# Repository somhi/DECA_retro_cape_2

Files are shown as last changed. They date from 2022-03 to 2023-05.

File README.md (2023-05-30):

# DECA Retro Cape 2

### (2 layer - MiSTer module SDRAM version)

DECA Retro Cape 2 is an addon for the [DECA FPGA](https://github.com/DECAfpga/DECA_board) development kit from Arrow/Terasic. The addon is connected to the Beaglebone Black connectors and hence the name of Cape as addons in the Beaglebone world are known.

This cape adds IO interface to the DECA board with all is needed to implement retro computers in this beautiful FPGA. Main IO interfaces are DB15 for VGA, PS2 for keyboard and mouse, DB9 for joystick, MiSTer memory connector, MiSTer user port.

Project has been developed with KiCAD 6.0. 

### Status

STATUS (29/01/23): Tests of v0.90 PCB work as expected, except for JP8 jumper (see [testing notes](testing_v0.90.md)). 

STATUS (26/12/22):  Finalized design v0.90 and production files including BOM and CPL.  See end of readme for changelog improvements from v0.71.

STATUS (07/04/22):  PCBs v0.71 received. Started [testing](testing.md).  Do not use without modifying voltage protections. Keyboard and Joystick (DB9 and USB3) protections must be redesigned in the next release.

STATUS (15/03/22):  prototype desing work finished. v0.71 gerbers sent to JLCPCB for manufacturing.

### Credits

I want to give credits to Tom Verbeure from whom I've taken his [original design  files](https://github.com/tomverbeure/arrow_deca_retro_cape) and adapted to my own design. Not much have been left from his design, but the name "DECA Retro Cape" remains.  

Thanks to rest of Hard Team DECA (C.Palmero & Rhoderik) and Telegram groups for the support received  during the development phase.

### **Schematic**

 [arrow_deca_retro_cape.pdf](arrow_deca_retro_cape.pdf) 

### **Features**

* VGA DAC 444
  *  Jumper to make use of VGA to SCART cables for 15 kHz RGB video

* Terasic 2x20 pin connector (for Mister SDRAM modules) + 3 pin for Dual SDRAM/SRAM 
* PS2 keyboard & mouse connectors
* Double Pmod (1/2) for peripherals (VGA Pmod, Hyperram, ...). 
  * Added four central pins for compatibility with RGB module of MuseLabs

* Pmod 3 (SPI + UART). Can act as Pmod host or peripheral 
* DETO Pmod (6 pin) for general usage (3 multiplexed pins)
* Game controller port (selection jumper to enable one or the other)
  * DB9 connector for joystick (Sega megadrive) (solder JP3 for A.Villena MiSTer DB9 addons)
  * USB3 User Port (for SNAC adapters SNES, Atari, ...)

* UART (Rx/Tx) header
* Power supply headers (5V, 3V3, 3V3 LDO, 2V5 LDO, 1V8 analog)

### **Important Usage notes**

* **Better do not connect/disconnect interfaces while the board is powered**
* **Do not connect two devices simultaneously into DB9 and USB3. Doing so may lead to unpredictabily results and damage the FPGA board**
* Prior to first power on it is required to solder jumpers JP2 (pins 3V3 and V) and JP7 (pin 5V and central pin). Read jumper selection notes below
* To use MiSTer memory modules place jumper JP6 to power supply 3V3 (and better left JP5 without jumper)
* Place jumper JP8 on desired interface (DB9 or USB3) for joystick usage. For USB3 jumper JP9 default is I/O.
* For USB3 SNAC adapters **do not** use the [SNAC level shifter adapter](https://manuferhi.com/p/snac-adapter-for-mister) as voltage protection is already included in the cape.
* For the rest of jumpers read jumper selection notes below. In case of doubt leave the default recommended position.
* There are a few signals with shared functions that cannot be used at the same time. Those signals are indicated in the PCB silkscreen with ( ) or *, **:
  * (1), (2) are shared between DETO PMOD and PMOD2
  * (3) is shared between DETO PMOD and the MUX signal of DB9 when JP3 is soldered
  * "**" only either DB9 or USB3 connector can be used at the same time (select it by jumper JP8)
  * "*" signals MISO, MOSI, CS2, SCK are shared between PMOD3 and the four pins of J2 and J3 located between pmods 2 & 3

### **Jumper Selection**

Defaults are OPEN (jumper not placed or not soldered) and CLOSED (jumper placed or soldered)

* JP1 jumper select Pmod 3 mode as peripheral (no jumper) or host (with jumper) [default is open]

* JP2 solder jumper selects 3V3 power supply from Deca board or from an optional LDO [default 3V3]. An optional 5V to 3V3 LDO can be soldered if the board cannot cope with the connected loads.

* JP3 solder jumper enables compatibility with Antonio Villena's MiSTer DB9 addons if soldered (MUX signal to allow two joysticks). Be careful, THIS OPTION IS UNTESTED [default open]

* JP4 jumper closed enables 5V at VGA pin 9 to make use of VGA to SCART cables for 15 kHz RGB video [default open]

* JP5 jumper closed power supply 2x20 Terasic connector with +5V [default open]

* JP6 jumper closed power supply 2x20 Terasic connector with +3V3 [default closed]

* JP7 solder jumper to select joystick power supply (5V or 2V5) [default 5V]

* JP8 jumper select either DB9 interface or USER IO (USB3). **Only one device can be connected at a time, otherwise might be damaged the FPGA board**

* JP9 jumper select USER IO pin 9 function (signal I/O or 3V3 power) [default I/O]

### 3D model

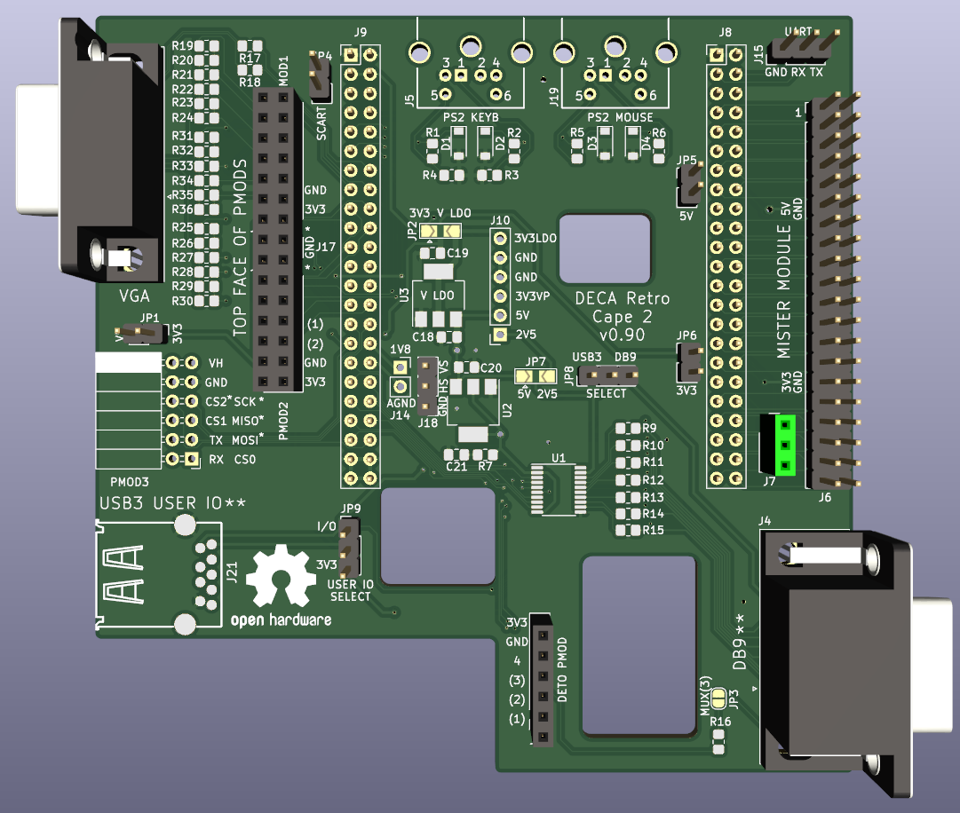
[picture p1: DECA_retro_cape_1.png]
DECA_retro_cape_1


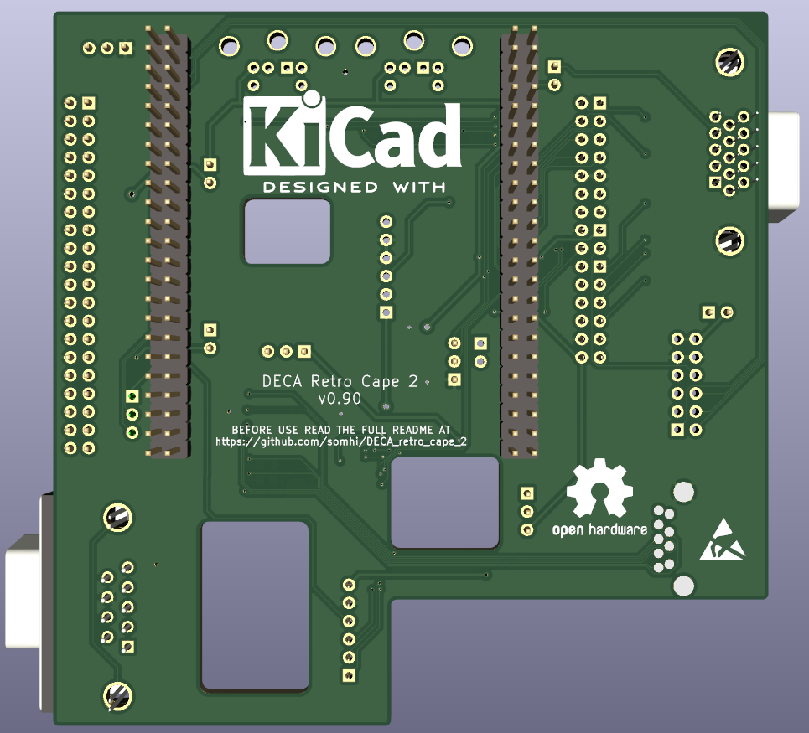
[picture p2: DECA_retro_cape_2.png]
DECA_retro_cape_2


### Changelog

v0.5  routed finalized

v0.6  MiSTer SDRAM only version. Changed to 2 layer board.

v0.62 all finished except VGA R2R schematic and routing

v0.65 power header changed, minor aesthetic changes

v0.68 added vga schematic and indiv. R 0805 into layout

v0.70 routing finished including vga

v0.71 finished prototype desing. Gerber sent to JLCPCB for manufacturing

v0.72 updated pinout spreadsheet and Readme with testing notes and improvements to be done

v0.75 Improvements from testing phase. 

* Changed footprint DB15 VGA to fit connectors from Aliexpress (was needed to bend pins)

* DETO Pmod connector change to socket type instead of pin type

* Silkscreen improvements: OSHW logo top

* Removed JTAG footprint

* Change limiting resistor of 180 Ohm to 510 Ohm (ps2 and db9)

* Power header reduced to 1 row instead of 2

* Optimized some traces

* Added solder pad JP3 to enable/disable compatibility with Antonio Villena's MiSTer DB9 addons

* JP4 jumper to enable 5V at VGA pin 9 to make use of VGA to SCART cables for 15 kHz RGB video

* Added PCB Hole for seeing Conf_done, Rx, Tx leds

v0.76 Double pmod 1&2 now compatible with pmod RGB module of MuseLabs (added 4 shared pins)

v0.77 Changes:

* Terasic connector: add jumpers on 5V and 3V3 to disconnect power, so I can connect it to other Terasic powered connectors.
* Replaced 3 pin jumper JP2 with solder jumper on 3V3 power selection
* Added solder jumper to select joystick power supply (5V or 2V5 from LDO)

v0.78 Changes:

* PS2 protection usign 3V9 Zener diodes (3V7 to 4V1).

* Added pulldown optional resistors for ps2 mouse

v0.80 Added Joystick shifter level protection with IC [TXS0108E](https://jlcpcb.com/partdetail/TexasInstruments-TXS0108EPWR/C17206) and jumper JP8 to select either DB9 or USB3 IO interface

v0.81 Improved Readme. Added readme notice in silkscreen. Removed v0.78 pulldown optional resistors for ps2 mouse (one of the pins has a physical pull-up resistor in fpga, so wouldn't work).

v0.82 generated BOM before installing jlcpcb-tools plugin

v0.83 Added jlcpcb parts with jlcpcb tools plugin 

v0.84 updated USB3 footprint

v0.85 updated references folder. choose zener 3V9 reference 

v0.86 updated datasheets, added R7 1Ω for increasing ESR on 2V5 LDO output with a ceramic capacitor instead of tantalum, updated BOM and nearly finished jlcpcb parts selection

v0.87 updated readme. Minor changes on schematic and PCB 

v0.90 Finalized design v0.90 and production files including BOM and CPL

### TODO improvements

* Reduce lenght of board in VGA wing side
* PS2:  Jumpers to activate pull-down resistors to enable USB mode
* If space is needed, make a common ps2 connector for keyb and mouse (ps2 splitter should be used). 
* Jumper on joystick DB9 pin 5 to change power supply to pin 7 in order to allow other joysticks like the Amiga one to work. Comment from telegram: "El Jumper lo puedes poner para cambiar la alimentación entre pin 5 y 7. De esa forma te funcionara ok los dos y podrás conectar cosas como el ratón de amiga. De los joysticks clásicos, la mayoría son totalmente pasivos y los quickshot II utilizan la alimentación de 5v para el autofire."
* SDRAM DQ14 and DQ15 position in newer MiSTer modules (xsds) are exchanged respect the older module (xs) I based my design from. This does not affect functionality at all as data in and data out are always in the same order.

### Testing

[Testings on v0.71 PCB](testing_v0.71.md)

[Testings on v0.90 PCB](testing_v0.90.md)

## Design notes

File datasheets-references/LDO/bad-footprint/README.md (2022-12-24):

U5 LDO 2V5 footprint do not correspond to LDO_2V5_NCV4274AST25T3G component

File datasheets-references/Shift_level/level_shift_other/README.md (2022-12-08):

Joystick shifter level protections

* jlc)  txs0108e, https://jlcpcb.com/partdetail/TexasInstruments-TXS0108EPWR/C17206
  74lvt245,  for 3v3
  jlc)  BSS138,    most polivalent edu, rhoderik alguns fallaven
  jlc) LSF0108  https://jlcpcb.com/partdetail/TexasInstruments-LSF0108PWR/C190219   2.5 V ↔ 3.3/5 V
  X) FXLP34P5XCT-ND     the ones used at UART C96

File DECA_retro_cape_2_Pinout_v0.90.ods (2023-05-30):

 |  |  |  | ←see pins in hidden columns |  |  |  |  |  | ←see pins in hidden columns
 |  | P9 |  |  |  |  |  | P8
 | GND | 1 | 2 | GND |  |  | GND | 1 | 2 | GND
 | 3V3 | 3 | 4 | 3V3 |  | pd7_fpga_en | UART_TXD | 3 | 4 | UART_RXD | pd6_core_reset
 | 5V | 5 | 6 | 5V |  | SPI_SS3 (OSD),pd10_cs | SPI_CS0_CLKBD | 5 | 6 | SPI_CS1 | CONF_DATA0 (IO), pd8_osd_en
 | 5V | 7 | 8 | 5V |  |  | DRAM_DQ[0] | 7 | 8 | DRAM_DQ[1]
10k pullup | PS2_MOUSE_DAT | 9 | 10 | PS2_MOUSE_CLK |  |  | DRAM_DQ[2] | 9 | 10 | DRAM_DQ[3]
 | PS2_KEYB_CLK | 11 | 12 | PS2_KEYB_DAT |  |  | DRAM_DQ[4] | 11 | 12 | DRAM_DQ[5]
 | VGA_VS / PMOD2[5] | 13 | 14 | VGA_HS / PMOD2[4] | RGB_PMOD_LCD_CLK |  | DRAM_DQ[6] | 13 | 14 | DRAM_DQ[7]
RGB_PMOD_g0 | VGA_B[0] / PMOD1[4] | 15 | 16 | VGA_R[0] / PMOD1[0] | RGB_PMOD_r0 |  | DRAM_DQ[14] | 15 | 16 | DRAM_DQ[15]
RGB_PMOD_b0 | VGA_G[0] / PMOD2[0] | 17 | 18 | VGA_G[3] / PMOD2[3] |  |  | DRAM_LDQM | 17 | 18 | DRAM_UDQM
 | VGA_G[2] / PMOD2[2] | 19 | 20 | VGA_G[1] / PMOD2[1] |  |  | DRAM_DQ[13] | 19 | 20 | DRAM_DQ[12]
RGB_PMOD_g3 | VGA_B[3] / PMOD1[7] | 21 | 22 | VGA_R[3] / PMOD1[3] | RGB_PMOD_r3 |  | DRAM_DQ[11] | 21 | 22 | DRAM_DQ[10]
 | VGA_B[2] / PMOD1[6] | 23 | 24 | VGA_R[2] / PMOD1[2] |  |  | DRAM_DQ[9] | 23 | 24 | DRAM_DQ[8]
 | VGA_B[1] / PMOD1[5] | 25 | 26 | VGA_R[1] / PMOD1[1] |  |  | DRAM_ADDR[12] | 25 | 26 | DRAM_CLK
SIGMA_L | DETO1 / PMOD2[6] | 27 | 28 | DETO2 / PMOD2[7] | SIGMA_R, BCLK |  | DRAM_ADDR[9] | 27 | 28 | DRAM_ADDR[11] | VREF slow
RGB_PMOD_R4, SPI_DO | SPI_MISO_WSDB | 29 | 30 | SPI_MOSI | SPI_DI, RGB_PMOD_G4 |  | DRAM_ADDR[7] | 29 | 30 | DRAM_ADDR[8]
RGB_PMOD_G5 | SPI_SCLK_DABD | 31 | 32 | A1V8 |  |  | DRAM_ADDR[5] | 31 | 32 | DRAM_ADDR[6]
AIN6/2V5 | JOYX_SEL_O | 33 | 34 | AGND |  |  | DRAM_WE_N | 33 | 34 | DRAM_ADDR[4]
AIN4/2V5 | JOY1_B2_P9 | 35 | 36 | JOY1_B1_P6 | AIN5/2V5 | LRCLK | DETO4 | 35 | 36 | DRAM_CKE
AIN2/2V5 | JOY1_UP | 37 | 38 | JOY1_DOWN | AIN3/2V5 |  | DRAM_CAS_N | 37 | 38 | DRAM_RAS_N
AIN0/2V5 | JOY1_RIGHT | 39 | 40 | JOY1_LEFT | AIN1/2V5 |  | DRAM_CS_N | 39 | 40 | DRAM_BA[0]
pll output, 3V3, DIN | DETO3_JOY_MUX | 41 | 42 | SPI_CS2 | SPI_SS2 (FPGA),pd9_io_en, RGB_PMOD_B0 |  | DRAM_BA[1] | 41 | 42 | DRAM_ADDR[10]
 | GND | 43 | 44 | GND |  |  | DRAM_ADDR[0] | 43 | 44 | DRAM_ADDR[1]
 | GND | 45 | 46 | GND |  |  | DRAM_ADDR[2] | 45 | 46 | DRAM_ADDR[3]
 | PMOD 1+2 (VGA/others) |  |  | PMOD3 (multicore) |  |  | 32 MB SDRAM embedded
 | 2 PS2 connectors + USB |  |  | DB9 (Joystick / AIN), USB3 Port
 | DETO PMOD (6 pin)
 | Design notes:
 | - Optional 3V3 from 5V (LDO 5 to 3V3)
 | - Header for power pins (5V, 3V3, GND, A1V8)
 | - Header DeTo for all 4 free pins (I2C, SPI, I2S, Sigma/delta)
 | - 40 pins Mister connector for external SRAM + 3 PINS
 | - USB3 User port shared with DB9
 | - test pins for VGA_VS/HS for connecting oscilloscope
 | - pulldown footprints in PS2 keyb for testing USB keyboards
 | USB3 Serial IO
 | https://boogermann.github.io/Bible_MiSTer/hardware/io-board/
 | https://manuferhi.com/search?q=snac |  |  |  |  |  | DECA RETRO CAPE 2 PINOUT v0.90
 | antoniovillena / MiSTer_DB9
 | https://github.com/antoniovillena/MiSTer_DB9

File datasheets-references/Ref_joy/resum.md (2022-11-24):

* mister: pull-ups al costat fpga, primer va la R limitadora
* R pull-up: 10k mister i minimig,  47k papilio

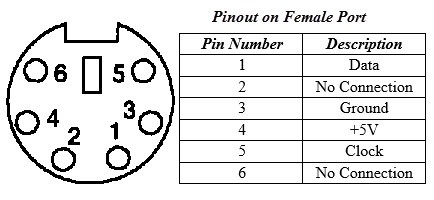
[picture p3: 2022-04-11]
datasheets-references/REF_circuits_connectors/ps2pinout.jpg

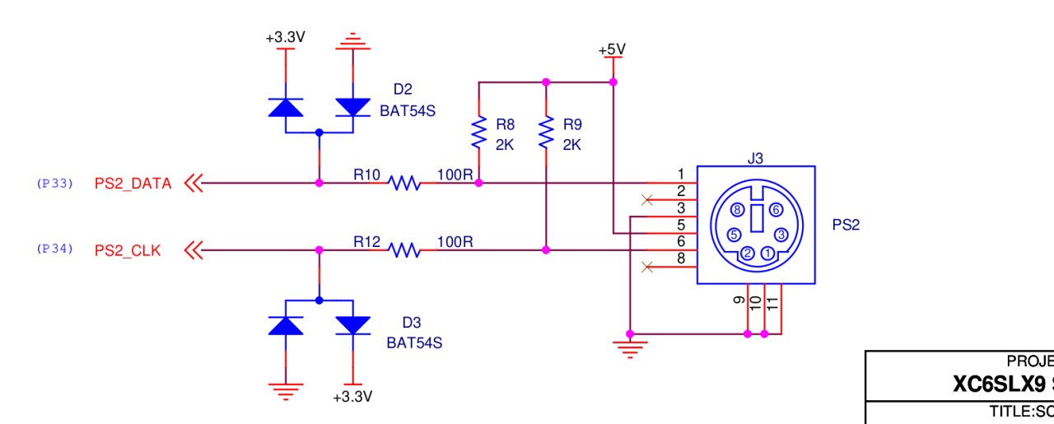
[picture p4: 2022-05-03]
datasheets-references/Ref_ps2/xc6slx9_placa_thesonders_BATs.jpg

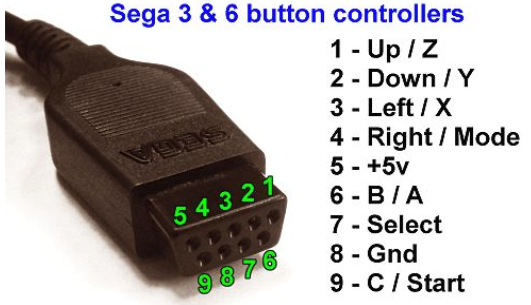
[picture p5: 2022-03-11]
datasheets-references/REF_circuits_connectors/db9-sega.png

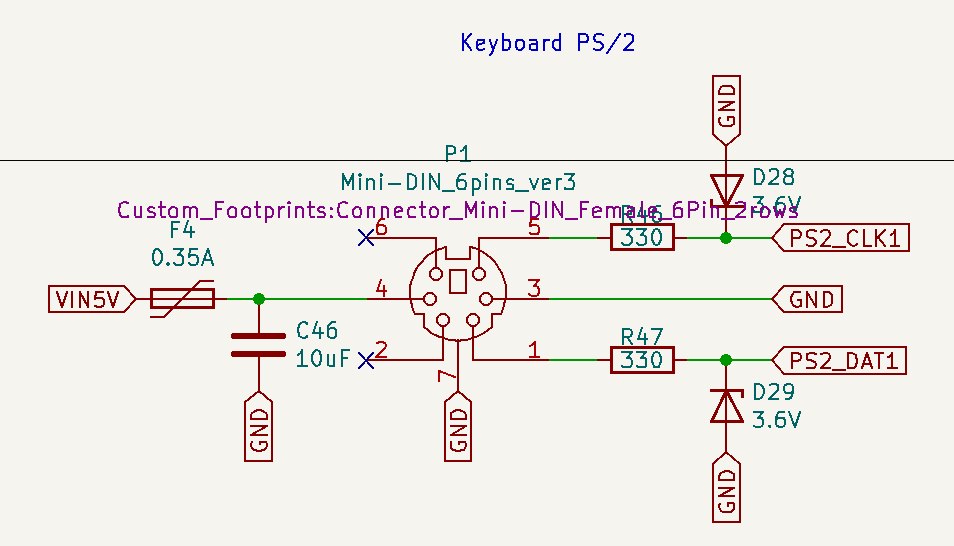
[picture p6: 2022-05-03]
datasheets-references/Ref_ps2/placa_minimig_zeners.jpg

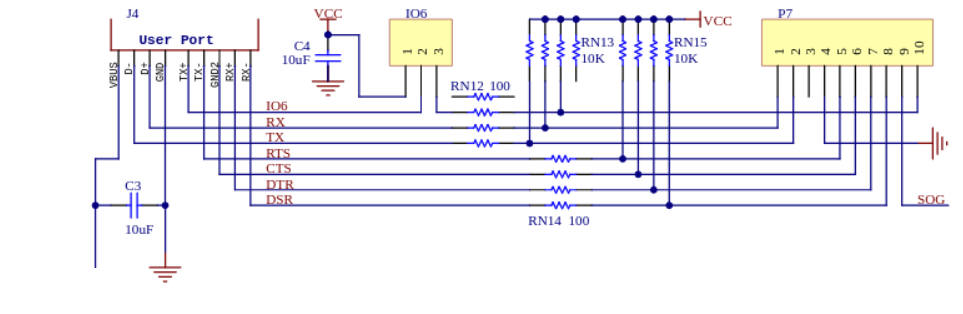
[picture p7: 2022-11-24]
datasheets-references/Ref_joy/mister_io_2.png

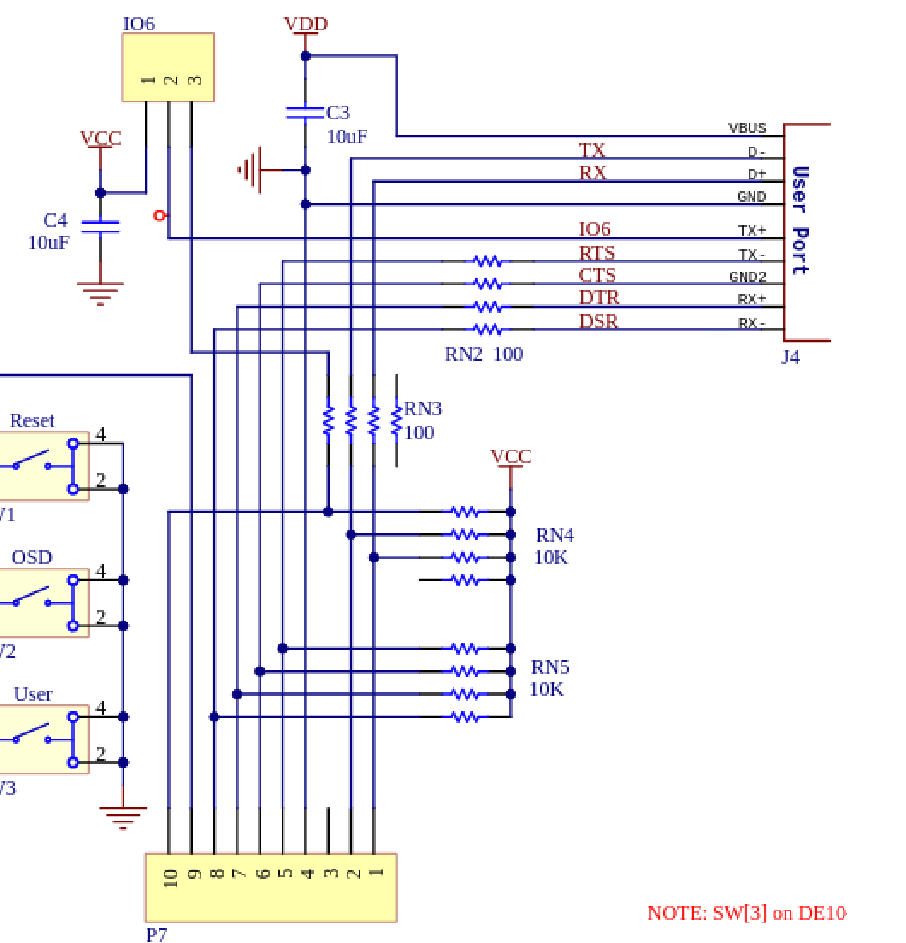
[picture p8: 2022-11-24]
datasheets-references/Ref_joy/mister_io_1.png

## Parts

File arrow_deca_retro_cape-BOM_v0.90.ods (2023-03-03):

Source: | /home/jordi/Kicad/a_DECA/DECA_retro_cape_2 (2-layer)/arrow_deca_retro_cape.kicad_sch
Date: | Sat 24 Dec 2022 20:08:38 CET
Tool: | Eeschema 6.0.9-8da3e8f707~117~ubuntu20.04.1
Generator: | /usr/share/kicad/plugins/bom_csv_grouped_by_value.py
Component Count: | 75
Individual Components:
Item | Qty | Reference(s) | Placed | https://jlcpcb.com/parts | notes | Value | LibPart | Footprint | Datasheet | Field4 | LCSC | Old | old_FP
 |  | C18 |  |  |  | 1uF | Device:C | Capacitor_SMD:C_0805_2012Metric_Pad1.18x1.45mm_HandSolder | ~
 |  | C19 |  |  |  | 10uF | Device:C | Capacitor_SMD:C_0805_2012Metric_Pad1.18x1.45mm_HandSolder | ~
 |  | C20 |  |  |  | 10uF | Device:C | Capacitor_SMD:C_0805_2012Metric_Pad1.18x1.45mm_HandSolder | ~
 |  | C21 |  |  |  | 22uF | Device:C | Capacitor_SMD:C_0805_2012Metric_Pad1.18x1.45mm_HandSolder | ~
 |  | D1 |  |  |  | BZT52C3V9 | :BZT52Bxx_1 | Diode_SMD:D_SOD-123 | https://datasheet.lcsc.com/lcsc/2005211208_LGE-BZT52C3V9_C545281.pdf
 |  | D2 |  |  |  | BZT52C3V9 | :BZT52Bxx_1 | Diode_SMD:D_SOD-123 | https://datasheet.lcsc.com/lcsc/2005211208_LGE-BZT52C3V9_C545281.pdf
 |  | D3 |  |  |  | BZT52C3V9 | :BZT52Bxx_1 | Diode_SMD:D_SOD-123 | https://datasheet.lcsc.com/lcsc/2005211208_LGE-BZT52C3V9_C545281.pdf
 |  | D4 |  |  |  | BZT52C3V9 | :BZT52Bxx_1 | Diode_SMD:D_SOD-123 | https://datasheet.lcsc.com/lcsc/2005211208_LGE-BZT52C3V9_C545281.pdf
 |  | J1 |  |  |  | DB15_Female_HighDensity_MountingHoles | Connector:DB15_Female_HighDensity_MountingHoles | Connector_Dsub:DSUB-15-HD_Female_Horizontal_P2.29x1.98mm_EdgePinOffset3.03mm_Housed_MountingHolesOffset4.94mm | ~
 |  | J2 |  |  |  | Conn_02x01 | Connector_Generic:Conn_02x01 | Connector_PinSocket_2.54mm:PinSocket_1x02_P2.54mm_Vertical | ~
 |  | J3 |  |  |  | Conn_02x01 | Connector_Generic:Conn_02x01 | Connector_PinSocket_2.54mm:PinSocket_1x02_P2.54mm_Vertical | ~
 |  | J4 |  |  |  | DB9_Male_MountingHoles | Connector:DB9_Male_MountingHoles | Connector_Dsub:DSUB-9_Male_Horizontal_P2.77x2.84mm_EdgePinOffset9.90mm_Housed_MountingHolesOffset11.32mm | ~
 |  | J5 |  |  |  | DINC_MIN_TM_6_1 | zxuno-eagle-import:DINC_MIN_TM_6_1 | ps2:DINC_MIN_TM_6_1PRIMARY
 |  | J6 |  |  |  | Conn_02x20_Odd_Even | Connector_Generic:Conn_02x20_Odd_Even | Connector_PinHeader_2.54mm:PinHeader_2x20_P2.54mm_Vertical | ~
 |  | J7 |  |  |  | Conn_01x03 | Connector_Generic:Conn_01x03 | Connector_PinSocket_2.54mm:PinSocket_1x03_P2.54mm_Vertical | ~
 |  | J8 |  |  |  | P8_Male | Connector_Generic:Conn_02x23_Odd_Even | Connector_PinHeader_2.54mm:PinHeader_2x23_P2.54mm_Vertical | ~
 |  | J9 |  |  |  | P9_Male | Connector_Generic:Conn_02x23_Odd_Even | Connector_PinHeader_2.54mm:PinHeader_2x23_P2.54mm_Vertical | ~
 |  | J10 |  |  |  | Conn_02x06_Odd_Even | Connector_Generic:Conn_01x06 | Connector_PinSocket_2.54mm:PinSocket_1x06_P2.54mm_Vertical | ~
 |  | J11 |  |  |  | PMOD1 | Connector_Generic:Conn_02x06_Top_Bottom | addon-edge-rpi-i2s-pmod:Pmod_2x06_P2.54mm_Vertical_2 | ~
 |  | J12 |  |  |  | PMOD2 | Connector_Generic:Conn_02x06_Top_Bottom | addon-edge-rpi-i2s-pmod:Pmod_2x06_P2.54mm_Vertical_2 | ~
 |  | J14 |  |  |  | Conn_01x02 | Connector_Generic:Conn_01x02 | Connector_PinSocket_2.54mm:PinSocket_1x02_P2.54mm_Vertical | ~
 |  | J15 |  |  |  | Conn_01x03 | Connector_Generic:Conn_01x03 | Connector_PinHeader_2.54mm:PinHeader_1x03_P2.54mm_Vertical | ~
 |  | J16 |  |  |  | Conn_01x06 | Connector_Generic:Conn_01x06 | Connector_PinSocket_2.54mm:PinSocket_1x06_P2.54mm_Vertical | ~
 |  | J17 |  |  |  | Conn_01x02 | Connector_Generic:Conn_01x02 | Connector_PinSocket_2.54mm:PinSocket_1x02_P2.54mm_Vertical | ~
 |  | J18 |  |  |  | Conn_01x03 | Connector_Generic:Conn_01x03 | Connector_PinHeader_2.54mm:PinHeader_1x03_P2.54mm_Vertical | ~
 |  | J19 |  |  |  | DINC_MIN_TM_6_1 | zxuno-eagle-import:DINC_MIN_TM_6_1 | ps2:DINC_MIN_TM_6_1PRIMARY
 |  | J20 |  |  |  | PMOD3 | Connector_Generic:Conn_02x06_Top_Bottom | addon-edge-rpi-i2s-pmod:PMOD_Female_Horizontal_2 | ~
 |  | J21 |  |  |  | USB3_A | Connector:USB3_A | varis:USB-3.0-TH_C69073 | ~ |  |  |  | Connector_USB:USB3_A_Molex_48393-001
 |  | J22 |  |  |  | Conn_01x03 | Connector_Generic:Conn_01x03 | Connector_PinHeader_2.54mm:PinHeader_1x03_P2.54mm_Vertical | ~
 |  | JP1 |  |  |  | Conn_01x02 | Connector_Generic:Conn_01x02 | Connector_PinHeader_2.54mm:PinHeader_1x02_P2.54mm_Vertical | ~
 |  | JP2 |  |  |  | SolderJumper_3_Open | Jumper:SolderJumper_3_Open | Jumper:SolderJumper-3_P2.0mm_Open_TrianglePad1.0x1.5mm | ~
 |  | JP3 |  |  |  | SolderJumper_2_Open | Jumper:SolderJumper_2_Open | Jumper:SolderJumper-2_P1.3mm_Open_RoundedPad1.0x1.5mm | ~
 |  | JP4 |  |  |  | Conn_01x02 | Connector_Generic:Conn_01x02 | Connector_PinHeader_2.54mm:PinHeader_1x02_P2.54mm_Vertical | ~
 |  | JP5 |  |  |  | Conn_01x02 | Connector_Generic:Conn_01x02 | Connector_PinHeader_2.54mm:PinHeader_1x02_P2.54mm_Vertical | ~
 |  | JP6 |  |  |  | Conn_01x02 | Connector_Generic:Conn_01x02 | Connector_PinHeader_2.54mm:PinHeader_1x02_P2.54mm_Vertical | ~
 |  | JP7 |  |  |  | SolderJumper_3_Open | Jumper:SolderJumper_3_Open | Jumper:SolderJumper-3_P2.0mm_Open_TrianglePad1.0x1.5mm | ~
 |  | JP8 |  |  |  | Conn_01x03 | Connector_Generic:Conn_01x03 | Connector_PinHeader_2.54mm:PinHeader_1x03_P2.54mm_Vertical | ~
 |  | R1 |  |  |  | 510 | Device:R | Resistor_SMD:R_0805_2012Metric_Pad1.20x1.40mm_HandSolder | ~ | Antonio entre 120 i 180 Ohm (47 també)
 |  | R2 |  |  |  | 510 | Device:R | Resistor_SMD:R_0805_2012Metric_Pad1.20x1.40mm_HandSolder | ~ | Antonio entre 120 i 180 Ohm (47 també)
 |  | R3 |  |  |  | DNI 4k7 | Device:R | Resistor_SMD:R_0805_2012Metric_Pad1.20x1.40mm_HandSolder | ~
 |  | R4 |  |  |  | DNI 4k7 | Device:R | Resistor_SMD:R_0805_2012Metric_Pad1.20x1.40mm_HandSolder | ~
 |  | R5 |  |  |  | 510 | Device:R | Resistor_SMD:R_0805_2012Metric_Pad1.20x1.40mm_HandSolder | ~ | Antonio entre 120 i 180 Ohm (47 també)
 |  | R6 |  |  |  | 510 | Device:R | Resistor_SMD:R_0805_2012Metric_Pad1.20x1.40mm_HandSolder | ~ | Antonio entre 120 i 180 Ohm (47 també)
 |  | R7 |  |  |  | 1 | Device:R | Resistor_SMD:R_0805_2012Metric_Pad1.20x1.40mm_HandSolder | ~
 |  | R9 |  |  |  | 510 | Device:R | Resistor_SMD:R_0805_2012Metric_Pad1.20x1.40mm_HandSolder | ~ | Antonio entre 120 i 180 Ohm (47 també)
 |  | R10 |  |  |  | 510 | Device:R | Resistor_SMD:R_0805_2012Metric_Pad1.20x1.40mm_HandSolder | ~ | Antonio entre 120 i 180 Ohm (47 també)
 |  | R11 |  |  |  | 510 | Device:R | Resistor_SMD:R_0805_2012Metric_Pad1.20x1.40mm_HandSolder | ~ | Antonio entre 120 i 180 Ohm (47 també)
 |  | R12 |  |  |  | 510 | Device:R | Resistor_SMD:R_0805_2012Metric_Pad1.20x1.40mm_HandSolder | ~ | Antonio entre 120 i 180 Ohm (47 també)
 |  | R13 |  |  |  | 510 | Device:R | Resistor_SMD:R_0805_2012Metric_Pad1.20x1.40mm_HandSolder | ~ | Antonio entre 120 i 180 Ohm (47 també)
 |  | R14 |  |  |  | 510 | Device:R | Resistor_SMD:R_0805_2012Metric_Pad1.20x1.40mm_HandSolder | ~ | Antonio entre 120 i 180 Ohm (47 també)
 |  | R15 |  |  |  | 510 | Device:R | Resistor_SMD:R_0805_2012Metric_Pad1.20x1.40mm_HandSolder | ~ | Antonio entre 120 i 180 Ohm (47 també)
 |  | R16 |  |  |  | 510 | Device:R | Resistor_SMD:R_0805_2012Metric_Pad1.20x1.40mm_HandSolder | ~ | Antonio entre 120 i 180 Ohm (47 també)
 |  | R17 |  |  |  | 180 | Device:R | Resistor_SMD:R_0805_2012Metric_Pad1.20x1.40mm_HandSolder | ~
 |  | R18 |  |  |  | 180 | Device:R | Resistor_SMD:R_0805_2012Metric_Pad1.20x1.40mm_HandSolder | ~
 |  | R19 |  |  |  | 2k | Device:R | Resistor_SMD:R_0805_2012Metric_Pad1.20x1.40mm_HandSolder | ~
 |  | R20 |  |  |  | 2k | Device:R | Resistor_SMD:R_0805_2012Metric_Pad1.20x1.40mm_HandSolder | ~
 |  | R21 |  |  |  | 2k | Device:R | Resistor_SMD:R_0805_2012Metric_Pad1.20x1.40mm_HandSolder | ~
 |  | R22 |  |  |  | 1k | Device:R | Resistor_SMD:R_0805_2012Metric_Pad1.20x1.40mm_HandSolder | ~
 |  | R23 |  |  |  | 1k | Device:R | Resistor_SMD:R_0805_2012Metric_Pad1.20x1.40mm_HandSolder | ~
 |  | R24 |  |  |  | 1k | Device:R | Resistor_SMD:R_0805_2012Metric_Pad1.20x1.40mm_HandSolder | ~
 |  | R25 |  |  |  | 2k | Device:R | Resistor_SMD:R_0805_2012Metric_Pad1.20x1.40mm_HandSolder | ~
 |  | R26 |  |  |  | 2k | Device:R | Resistor_SMD:R_0805_2012Metric_Pad1.20x1.40mm_HandSolder | ~
 |  | R27 |  |  |  | 2k | Device:R | Resistor_SMD:R_0805_2012Metric_Pad1.20x1.40mm_HandSolder | ~
 |  | R28 |  |  |  | 1k | Device:R | Resistor_SMD:R_0805_2012Metric_Pad1.20x1.40mm_HandSolder | ~
 |  | R29 |  |  |  | 1k | Device:R | Resistor_SMD:R_0805_2012Metric_Pad1.20x1.40mm_HandSolder | ~
 |  | R30 |  |  |  | 1k | Device:R | Resistor_SMD:R_0805_2012Metric_Pad1.20x1.40mm_HandSolder | ~
 |  | R31 |  |  |  | 2k | Device:R | Resistor_SMD:R_0805_2012Metric_Pad1.20x1.40mm_HandSolder | ~
 |  | R32 |  |  |  | 2k | Device:R | Resistor_SMD:R_0805_2012Metric_Pad1.20x1.40mm_HandSolder | ~
 |  | R33 |  |  |  | 2k | Device:R | Resistor_SMD:R_0805_2012Metric_Pad1.20x1.40mm_HandSolder | ~
 |  | R34 |  |  |  | 1k | Device:R | Resistor_SMD:R_0805_2012Metric_Pad1.20x1.40mm_HandSolder | ~
 |  | R35 |  |  |  | 1k | Device:R | Resistor_SMD:R_0805_2012Metric_Pad1.20x1.40mm_HandSolder | ~
 |  | R36 |  |  |  | 1k | Device:R | Resistor_SMD:R_0805_2012Metric_Pad1.20x1.40mm_HandSolder | ~
 |  | U1 |  |  |  | TXS0108EPW | Logic_LevelTranslator:TXS0108EPW | Package_SO:TSSOP-20_4.4x6.5mm_P0.65mm | www.ti.com/lit/ds/symlink/txs0108e.pdf
 |  | U4 |  |  |  | LM1117-3.3 | Regulator_Linear:LM1117-3.3 | Package_TO_SOT_SMD:SOT-223-3_TabPin2 | http://www.ti.com/lit/ds/symlink/lm1117.pdf
 |  | U5 |  |  |  | AMS1117-2.5 | Regulator_Linear:LM1117-3.3 | Package_TO_SOT_SMD:SOT-223-3_TabPin2 | http://www.ti.com/lit/ds/symlink/lm1117.pdf |  |  | LM1117-2.5
 |  |  |  |  | SMD = assembled by JLCPCB
Collated Components: |  |  |  |  | DNI = Do Not Install
Item | Qty | Reference(s) | Placed | https://jlcpcb.com/parts | notes | Value | LibPart | Footprint | Datasheet | Field4 | LCSC | Old | old_FP
1 | 1 | C18 |  | C28323 | SMD | 1uF | Device:C | Capacitor_SMD:C_0805_2012Metric_Pad1.18x1.45mm_HandSolder | ~
2 | 2 | C19, C20 |  | C15850 | SMD | 10uF | Device:C | Capacitor_SMD:C_0805_2012Metric_Pad1.18x1.45mm_HandSolder | ~
3 | 1 | C21 |  | C45783 | SMD | 22uF | Device:C | Capacitor_SMD:C_0805_2012Metric_Pad1.18x1.45mm_HandSolder | ~
4 | 4 | D1, D2, D3, D4 |  | C107594 | SMD | BZT52C3V9 | :BZT52Bxx_1 | Diode_SMD:D_SOD-123 | https://datasheet.lcsc.com/lcsc/2005211208_LGE-BZT52C3V9_C545281.pdf
5 | 1 | J1 |  |  | https://es.aliexpress.com/item/4000945346804.html | DB15_Female_HighDensity_MountingHoles | Connector:DB15_Female_HighDensity_MountingHoles | Connector_Dsub:DSUB-15-HD_Female_Horizontal_P2.29x1.98mm_EdgePinOffset3.03mm_Housed_MountingHolesOffset4.94mm | ~
6 | 2 | J2, J3 |  |  | DNI | Conn_02x01 | Connector_Generic:Conn_02x01 | Connector_PinSocket_2.54mm:PinSocket_1x02_P2.54mm_Vertical | ~
7 | 1 | J4 |  |  | https://es.aliexpress.com/item/33032596922.html | DB9_Male_MountingHoles | Connector:DB9_Male_MountingHoles | Connector_Dsub:DSUB-9_Male_Horizontal_P2.77x2.84mm_EdgePinOffset9.90mm_Housed_MountingHolesOffset11.32mm | ~
8 | 2 | J5, J19 |  |  | https://es.aliexpress.com/item/1005003218198326.html | DINC_MIN_TM_6_1 | zxuno-eagle-import:DINC_MIN_TM_6_1 | ps2:DINC_MIN_TM_6_1PRIMARY
9 | 1 | J6 |  |  | https://es.aliexpress.com/item/32759414721.html | Conn_02x20_Odd_Even | Connector_Generic:Conn_02x20_Odd_Even | Connector_PinHeader_2.54mm:PinHeader_2x20_P2.54mm_Vertical | ~
10 | 1 | J7 |  |  | https://es.aliexpress.com/item/1005003183490511.html | Conn_01x03 | Connector_Generic:Conn_01x03 | Connector_PinSocket_2.54mm:PinSocket_1x03_P2.54mm_Vertical | ~
11 | 1 | J8 |  |  | https://es.aliexpress.com/item/32759414721.html | P8_Male | Connector_Generic:Conn_02x23_Odd_Even | Connector_PinHeader_2.54mm:PinHeader_2x23_P2.54mm_Vertical | ~
12 | 1 | J9 |  |  | https://es.aliexpress.com/item/32759414721.html | P9_Male | Connector_Generic:Conn_02x23_Odd_Even | Connector_PinHeader_2.54mm:PinHeader_2x23_P2.54mm_Vertical | ~
13 | 1 | J10 |  |  | DNI | Conn_02x06_Odd_Even | Connector_Generic:Conn_01x06 | Connector_PinSocket_2.54mm:PinSocket_1x06_P2.54mm_Vertical | ~
14 | 1 | J11 |  | 2x15 socket |  | PMOD1 | Connector_Generic:Conn_02x06_Top_Bottom | addon-edge-rpi-i2s-pmod:Pmod_2x06_P2.54mm_Vertical_2 | ~
15 | 1 | J12 |  | 2x15 socket |  | PMOD2 | Connector_Generic:Conn_02x06_Top_Bottom | addon-edge-rpi-i2s-pmod:Pmod_2x06_P2.54mm_Vertical_2 | ~
16 | 2 | J14, J17 |  | J14 DNI, J17 2x15 socket | https://es.aliexpress.com/item/1005001914815306.html | Conn_01x02 | Connector_Generic:Conn_01x02 | Connector_PinSocket_2.54mm:PinSocket_1x02_P2.54mm_Vertical | ~
17 | 4 | J15, J18, JP8, JP9 |  |  | https://es.aliexpress.com/item/32759414721.html | Conn_01x03 | Connector_Generic:Conn_01x03 | Connector_PinHeader_2.54mm:PinHeader_1x03_P2.54mm_Vertical | ~
18 | 1 | J16 |  |  | https://es.aliexpress.com/item/1005001914815306.html | Conn_01x06 | Connector_Generic:Conn_01x06 | Connector_PinSocket_2.54mm:PinSocket_1x06_P2.54mm_Vertical | ~
19 | 1 | J20 |  |  | https://es.aliexpress.com/item/32890057619.html | PMOD3 | Connector_Generic:Conn_02x06_Top_Bottom | addon-edge-rpi-i2s-pmod:PMOD_Female_Horizontal_2 | ~
20 | 1 | J21 |  | C69073 | https://es.aliexpress.com/item/32663319053.html | USB3_A | Connector:USB3_A | varis:USB-3.0-TH_C69073 | ~ |  |  |  | Connector_USB:USB3_A_Molex_48393-001
21 | 4 | JP1, JP4, JP5, JP6 |  |  | https://es.aliexpress.com/item/32759414721.html | Conn_01x02 | Connector_Generic:Conn_01x02 | Connector_PinHeader_2.54mm:PinHeader_1x02_P2.54mm_Vertical | ~
22 | 2 | JP2, JP7 |  |  | -- | SolderJumper_3_Open | Jumper:SolderJumper_3_Open | Jumper:SolderJumper-3_P2.0mm_Open_TrianglePad1.0x1.5mm | ~
23 | 1 | JP3 |  |  | -- | SolderJumper_2_Open | Jumper:SolderJumper_2_Open | Jumper:SolderJumper-2_P1.3mm_Open_RoundedPad1.0x1.5mm | ~
24 | 12 | R1, R2, R5, R6, R9, R10, R11, R12, R13, R14, R15, R16 |  | C17734 | SMD | 510 | Device:R | Resistor_SMD:R_0805_2012Metric_Pad1.20x1.40mm_HandSolder | ~ | Antonio entre 120 i 180 Ohm (47 també)
25 | 2 | R3, R4 |  |  | DNI | DNI 4k7 | Device:R | Resistor_SMD:R_0805_2012Metric_Pad1.20x1.40mm_HandSolder | ~
26 | 1 | R7 |  | C25271 | SMD | 1 | Device:R | Resistor_SMD:R_0805_2012Metric_Pad1.20x1.40mm_HandSolder | ~
27 | 2 | R17, R18 |  | C25270 | SMD | 180 | Device:R | Resistor_SMD:R_0805_2012Metric_Pad1.20x1.40mm_HandSolder | ~
28 | 9 | R19, R20, R21, R25, R26, R27, R31, R32, R33 |  | C17604 | SMD | 2k | Device:R | Resistor_SMD:R_0805_2012Metric_Pad1.20x1.40mm_HandSolder | ~
29 | 9 | R22, R23, R24, R28, R29, R30, R34, R35, R36 |  | C17513 | SMD | 1k | Device:R | Resistor_SMD:R_0805_2012Metric_Pad1.20x1.40mm_HandSolder | ~
30 | 1 | U1 |  | C17206 | SMD | TXS0108EPWR | Logic_LevelTranslator:TXS0108EPW | Package_SO:TSSOP-20_4.4x6.5mm_P0.65mm | www.ti.com/lit/ds/symlink/txs0108e.pdf
31 | 1 | U3 |  |  | DNI | LM1117-3.3 | Regulator_Linear:LM1117-3.3 | Package_TO_SOT_SMD:SOT-223-3_TabPin2 | http://www.ti.com/lit/ds/symlink/lm1117.pdf
32 | 1 | U2 |  | C12087 | SMD | AMS1117-2.5 | Regulator_Linear:LM1117-3.3 | Package_TO_SOT_SMD:SOT-223-3_TabPin2 | http://www.ti.com/lit/ds/symlink/lm1117.pdf |  |  | LM1117-2.5
 | 6 | JUMPERS |  |  | https://es.aliexpress.com/item/10000002338839.html | JUMPERS

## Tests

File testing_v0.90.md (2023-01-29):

# Testing DECA Retro Cape 2 

## Tests v0.90 PCB

- [x] DB15 VGA connector
  - [x] SCART JP4 jumper (5V on pin 9) to activate TVs for 15 KHz video output (test: PCXT, Pooyan)
  
- [x] Mister module connector: tested with dual memory module and XS 2.2
  - [x] 3 extra pins. Test with dual memory module
  - [x] JP6 jumper for 3V3 power supply
  - [x] JP5 jumper for 5V power supply
  
- [x] PS2 mouse: PCXT, MiSTery
  - [x] voltage on FPGA pins < 3V3 (Test: 2.75 V)
  
- [x] PS2 keyboard: all cores tested
  - [x] voltage on FPGA pins < 3V3.  (Test: 3.16V)
  
- [x] DB9 / USB3
  
  - [x] Without joystick connected, keyboard is working fine
  
  - [x] DB9 joystick  (tested with megadrive 6 buttons) (Pooyan, SNES 6 buttons test)
    - [x] voltage on FPGA pins < 2V5  (test: 2.49V)
    - [ ] DB9 Mux JP3 solder jumper for Villena addons compatibility  **(untested)**
  
  - [x] USB3 user IO: tested with USB3 to DB9 SNAC  (tested with megadrive 6 buttons) (SNES 6 buttons test)
    - [x] voltage on FPGA pins < 2V5
    - [x] JP9 I/O 
    - [ ] JP9 3V3 **(untested)**

  - [x] DB9 / USB3 JP8 jumper selection  **(gives undesired results)**
  
    Without any jumper placed, if I connect a megadrive pad either to DB9 or USB3 it works and the corresponing pin of the jumper (USB3 / DB9)  gets 5V though the gamepad itself.
  
    **CAUTION: Do not connect devices simultaneously into DB9 and USB3 connectors. Doing so may lead to unpredictabily results and damage the FPGA board.**
  
- [x] PMOD
  - [x] Pmod 1 (tested with Pmod VGA digilent)

  - [x] Pmod 2 (tested with Pmod VGA digilent)

  - [x] Pmod 3
    - [x] JP1 jumper to act as Pmod host

  - [ ] Pmod DETO

  - [x] Extended pins for Pmod1 & Pmod2 

    - [x] 5V
    - [ ] 4 extra central pins for e.g.  RGB module of MuseLabs

- [x] UART Serial connector J15

- [x] Power supply connector J10
  - [x] 2V5 (LDO)
  - [x] 5V (FPGA)
  - [x] 3V3VP (FPGA)
  - [x] GND
  - [x] 3V3LDO (LDO) (0V as LDO is not assembled)

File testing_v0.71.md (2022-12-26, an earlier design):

# Testing DECA Retro Cape 2 

## Tests v0.71 PCB

* 2V5 LDO gives 2.5 without connecting Deca. With Deca connected output goes to 2.74 V. With Sega megadrive connected goes to 2.64 V. With Atari joystick 2.74V.

**19/04/22** Test circuit amb BATs

* En buit, pin ps2_keyb_dat, a 4.8V tant amb el BAT abans con després de la R (idem resultats amb R 180 i amb R 470)

* En càrrega (deca connectada), pin ps2_keyb_dat, a 4.8V tant amb el BAT abans con després de la R (idem 180 i 470)

* Posant R pullup (i sense BATs) tal com esquema Tom Verbeure també obtinc 5V als pins FPGA. Provat amb 4k7 i 10k.    També he provat de simular impedància FPGA posant una R de 1 MOhm entre pin FPGA i GND, amb resultats similars.

**25/04/22**  Test esquema tipus Tom Verbeure retrocape, amb Deca connectada a la cape

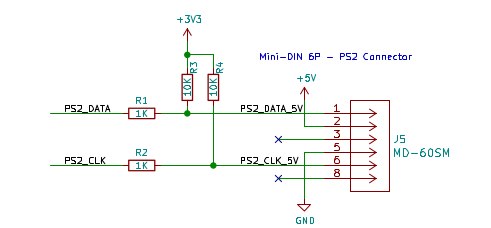
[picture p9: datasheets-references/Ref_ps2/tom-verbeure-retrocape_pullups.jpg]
tom-verbeure-retrocape_pullups


										Valors resistències provades: R1/R2 = 470 Ohm, R3/R4 = 4k7 Ohm 

* Amb jumper V-LDO  (Alimentació LDO) tot el rail de 3V3 es posa a 4.6V 
* Amb jumper V-3V3  (alimentació Deca) el rail de 3V3 continua a 3V3 
  * Pin PS2 FPGA està a 4.6 V

**25/04/22** Proves divisors de tensió

* R1 470, R2 2k   només funciona teclat Logitech (usb/ps2 i l'altre no funcionen). Tensió pins fpga = 2.54V

**12/05/22**

* <u>Zener 3+0.7 V gives at FPGA 2.4V for my mouse and 2.8V for my keyboard, and both are working.</u>
  * zener 3V+0.7V,   R470,  mouse ps2 -> fpga pins 2.4V mouse, 2.7V keyboard
  * zener 3V+0.7V,   R180,  mouse ps2 -> fpga pins 2.5V mouse (dif 0.08V), 2.7V keyboard (dif 0.03V)
  * zener 3V,    R470, keyboard -> fpga pins 2.0V keyboard, 1.8V mouse 

* If I apply 3V3 from Deca to the BAT54 circuit it works as expected. At FPGA we have 3.6V.
  * If we could apply 3V to the BATs then we would have 3V3 at the FPGA ps2 inputs
  * When we give 3V3 or 2V5 from LDO or from a voltage divider to the BATs, then the voltage from the  BATs and all it's rail changes to 4V7

Summary:

* <u>For ps2 use 3V6 (or 4V) zeners.</u> 
  * <u>BAT54 could be used with 3V3 supplied by Deca.</u> (put Resistors in front of BAT54, not after)

* For joystick 
  * Zeners work Ok with joy connected. When joy is disconnected, fpga input is 1V and it does not work applying weak pull-ups or physical pull-ups before or after the 510 resistor.
  * BAT54 does not work well with 2V5 from LDO or with a voltage divider from 5V (1k resistor R1, R2 values) as the 2V5 rail changes to 4.7V
  * If we could accept 3V3  at fpga inputs then it would work if we power supply from Deca 3V3 but it is not the case as we can only accept 2V5.

**Tests 13/05/22** joystick

* tested zener circuit with limiting resitor before and after the zener.  Weak Pull-up still not working.
* tryed quartus pin planner combinations of 2V5 schmidt trigger, 4 mA, pull-up, without success. 
  1.8V cannot be selected for a 2V5 bank.

**Test 15/05/22** joystick

* Tornat a provar BATs amb R 1k entre fpga i R.  Mateixos efectes.
* Provat de posar un diode a la part de 5V. idem
* Provat de posar un diode a la sortida de 3V3 i alimentar el circuit de 2V5 (sense ldo). idem resultat puja tensió a 4.8V

**24/12/22**

* <u>Zener 3.9 V gives at FPGA 2.4V for my mouse and 2.8V for my keyboard, and both are working.</u>

  * zener 3.9V,   R470,  mouse ps2 -> fpga pins 2.75V mouse, 3.13V keyboard

  * zener 3.9V,   R510,  mouse ps2 -> fpga pins 2.8V mouse, 3.18V keyboard  (not same zener)

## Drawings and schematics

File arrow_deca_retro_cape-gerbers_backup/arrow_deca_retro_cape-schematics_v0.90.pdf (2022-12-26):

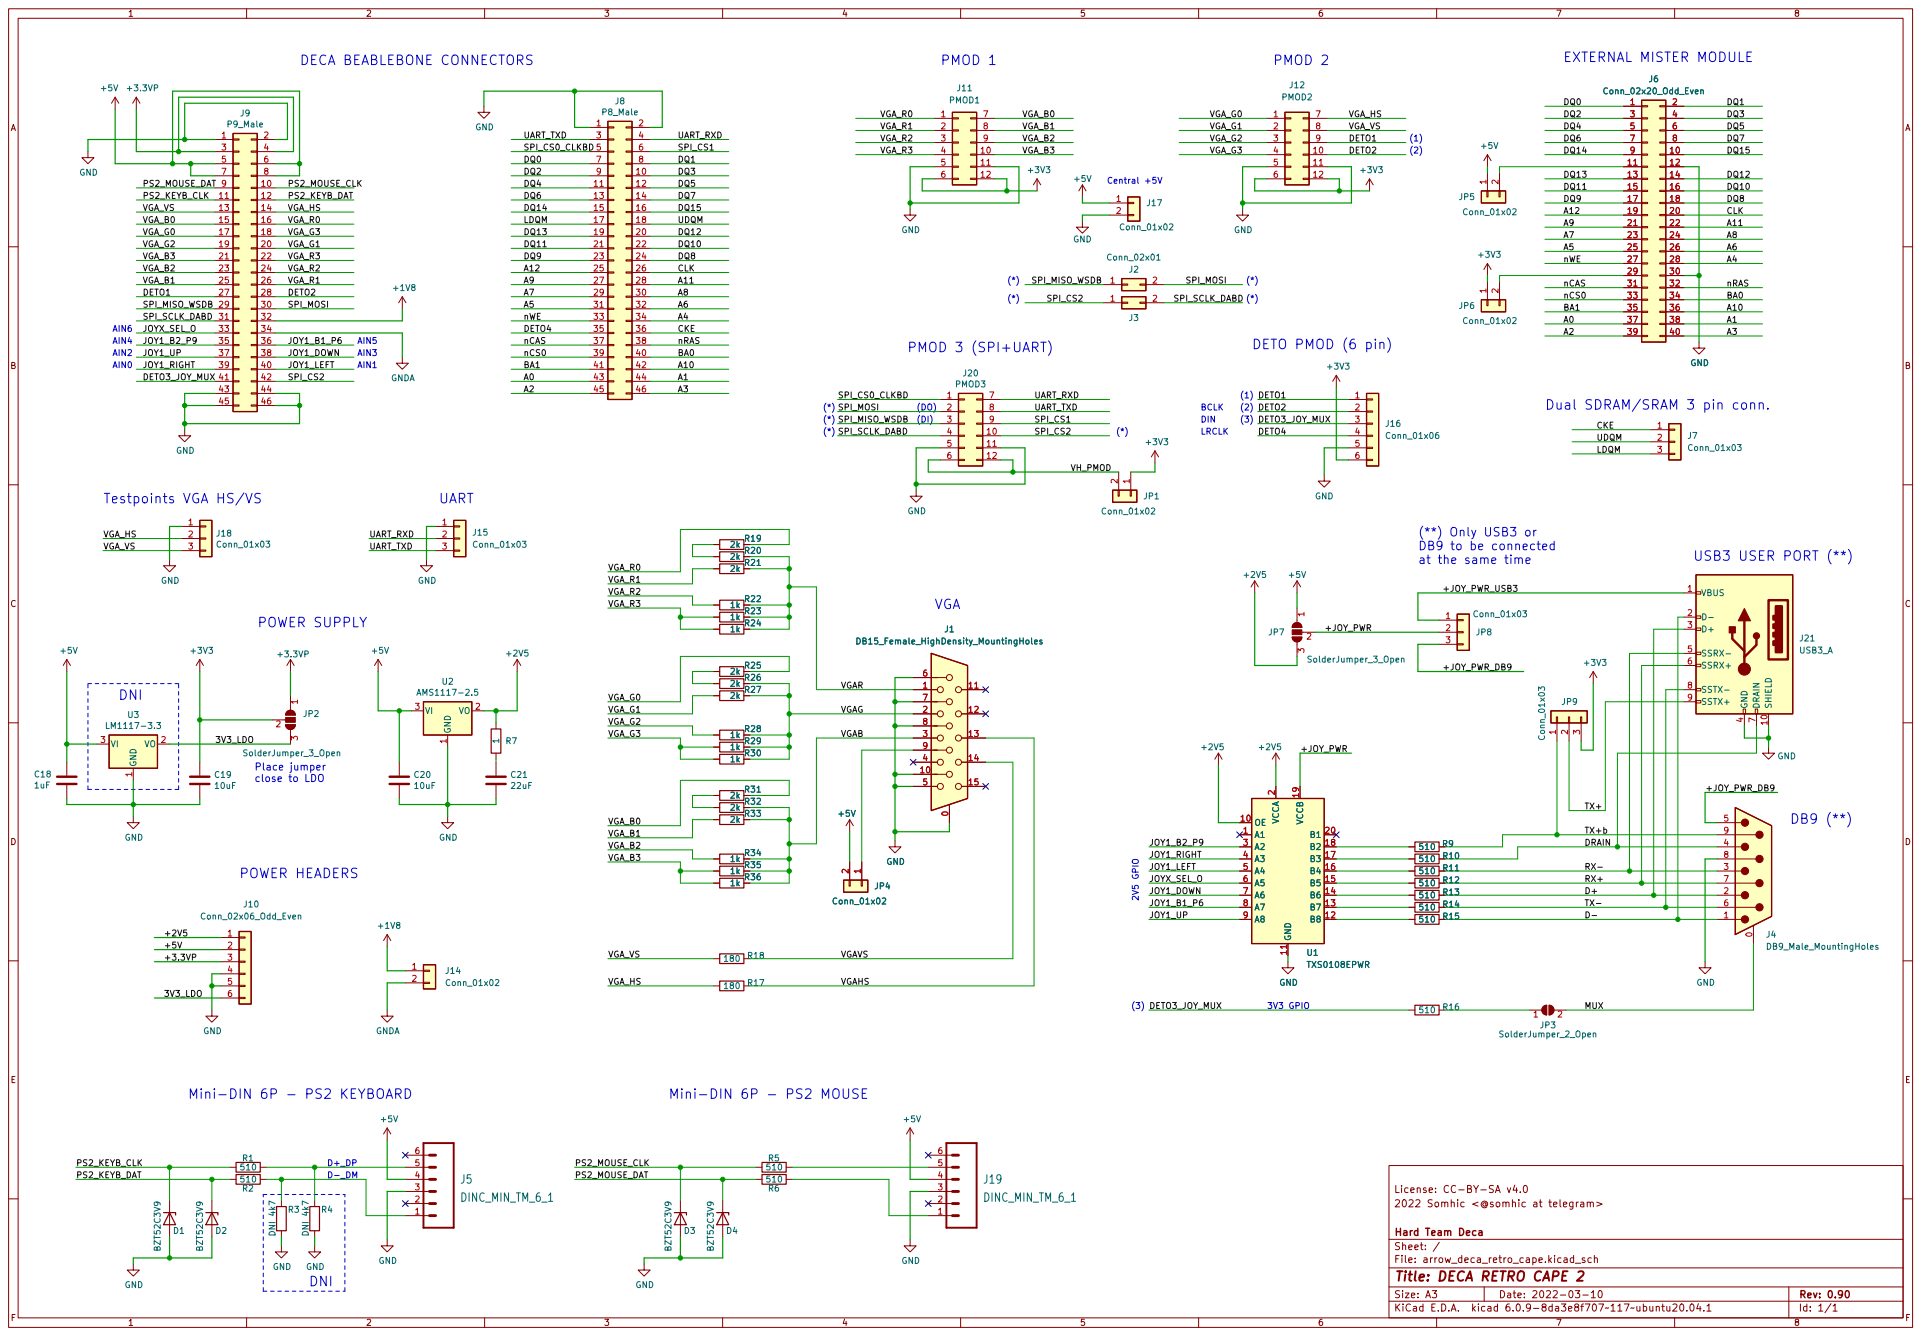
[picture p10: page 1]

Testpoints VGA HS/VS

License: CC-BY-SA v4.0
2022 Somhic <@somhic at telegram>

File: arrow_deca_retro_cape.kicad_sch Sheet: / Hard Team Deca

Id: 1/1 Title: DECA RETRO CAPE 2

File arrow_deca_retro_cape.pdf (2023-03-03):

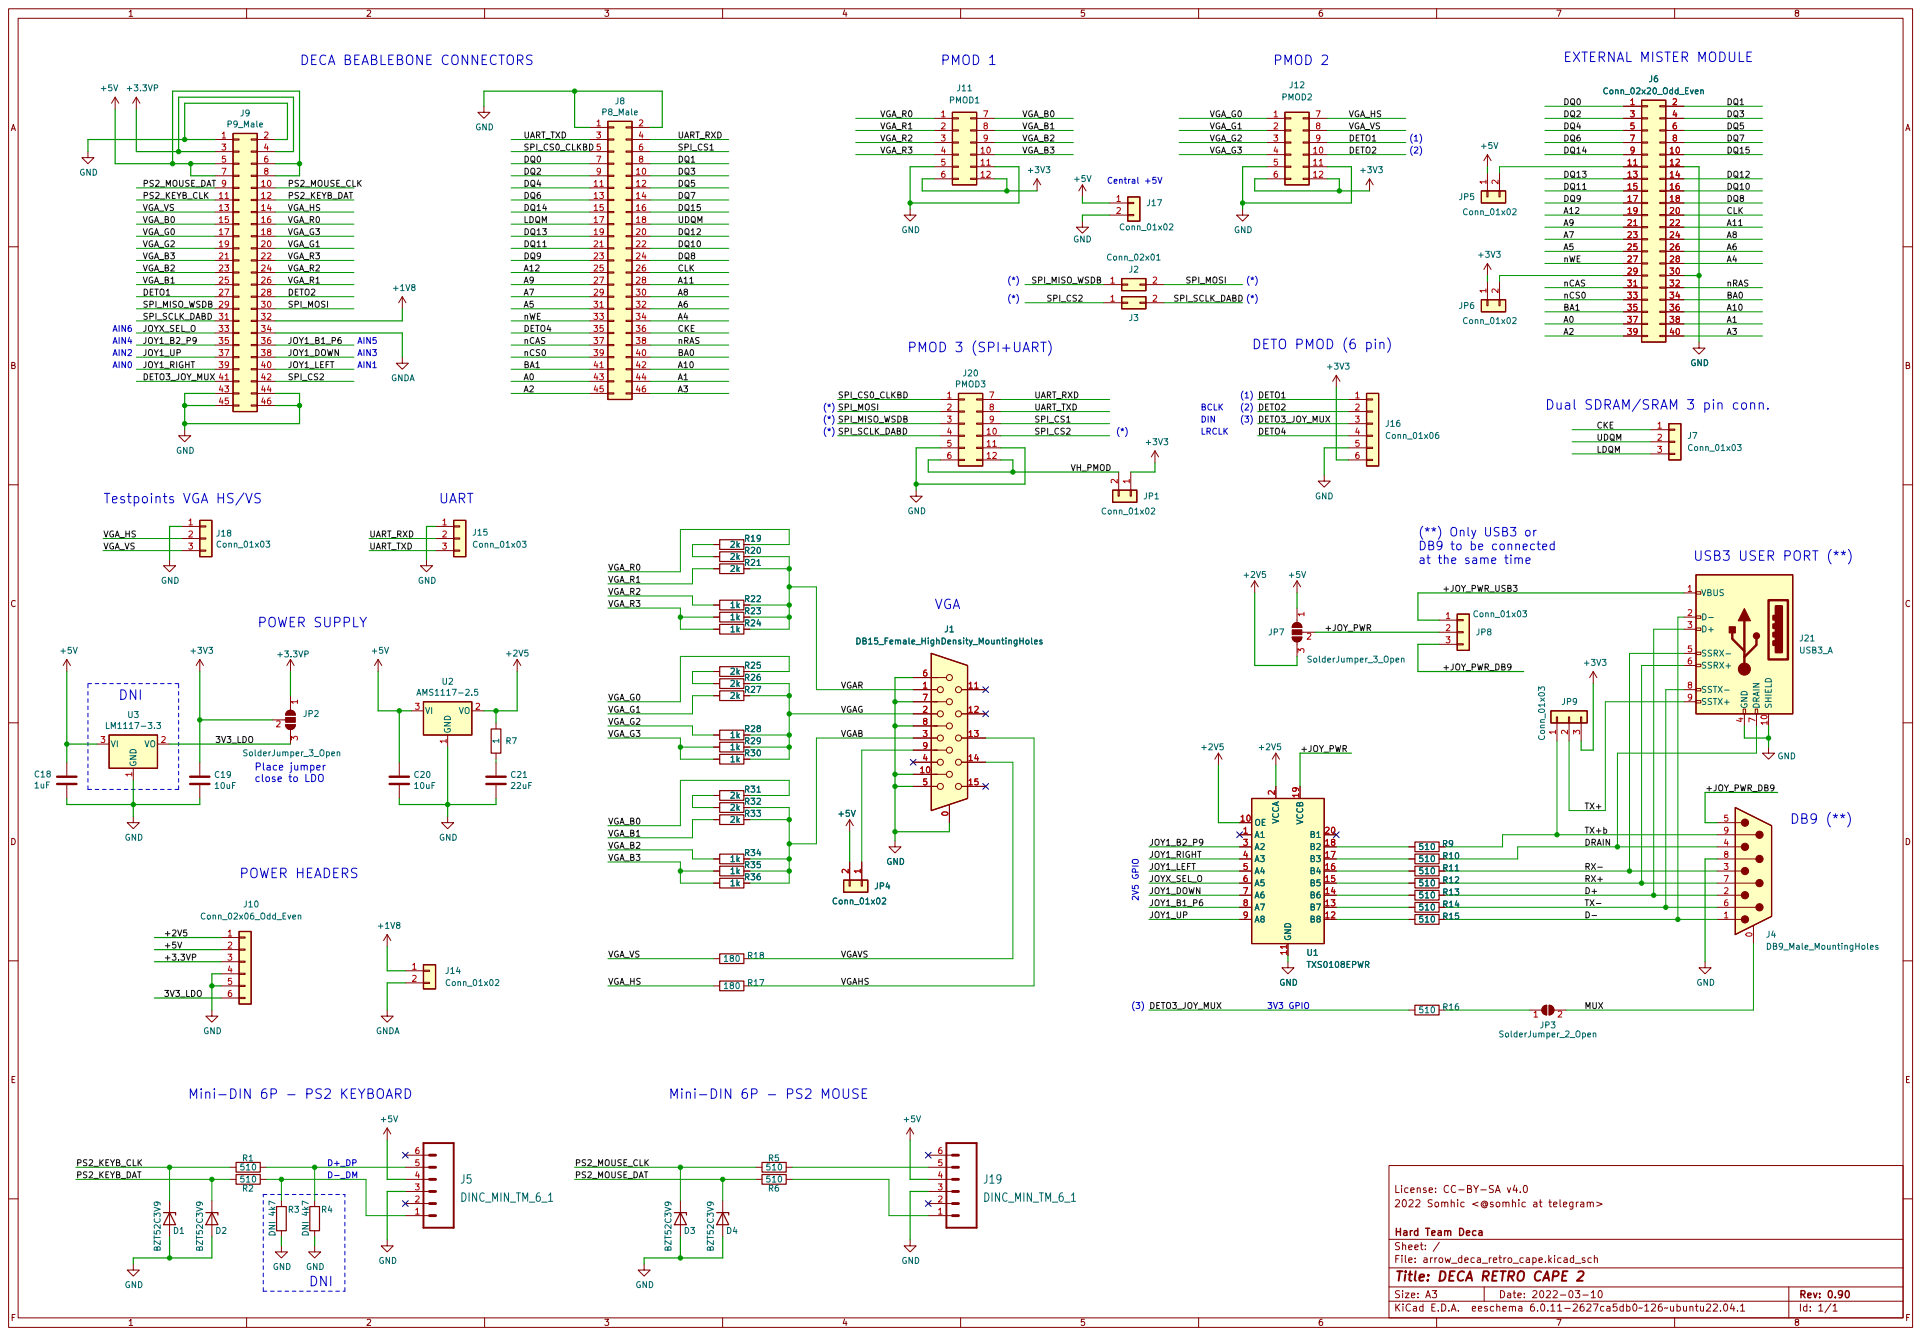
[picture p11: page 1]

at the same time

Id: 1/1 Title: DECA RETRO CAPE 2

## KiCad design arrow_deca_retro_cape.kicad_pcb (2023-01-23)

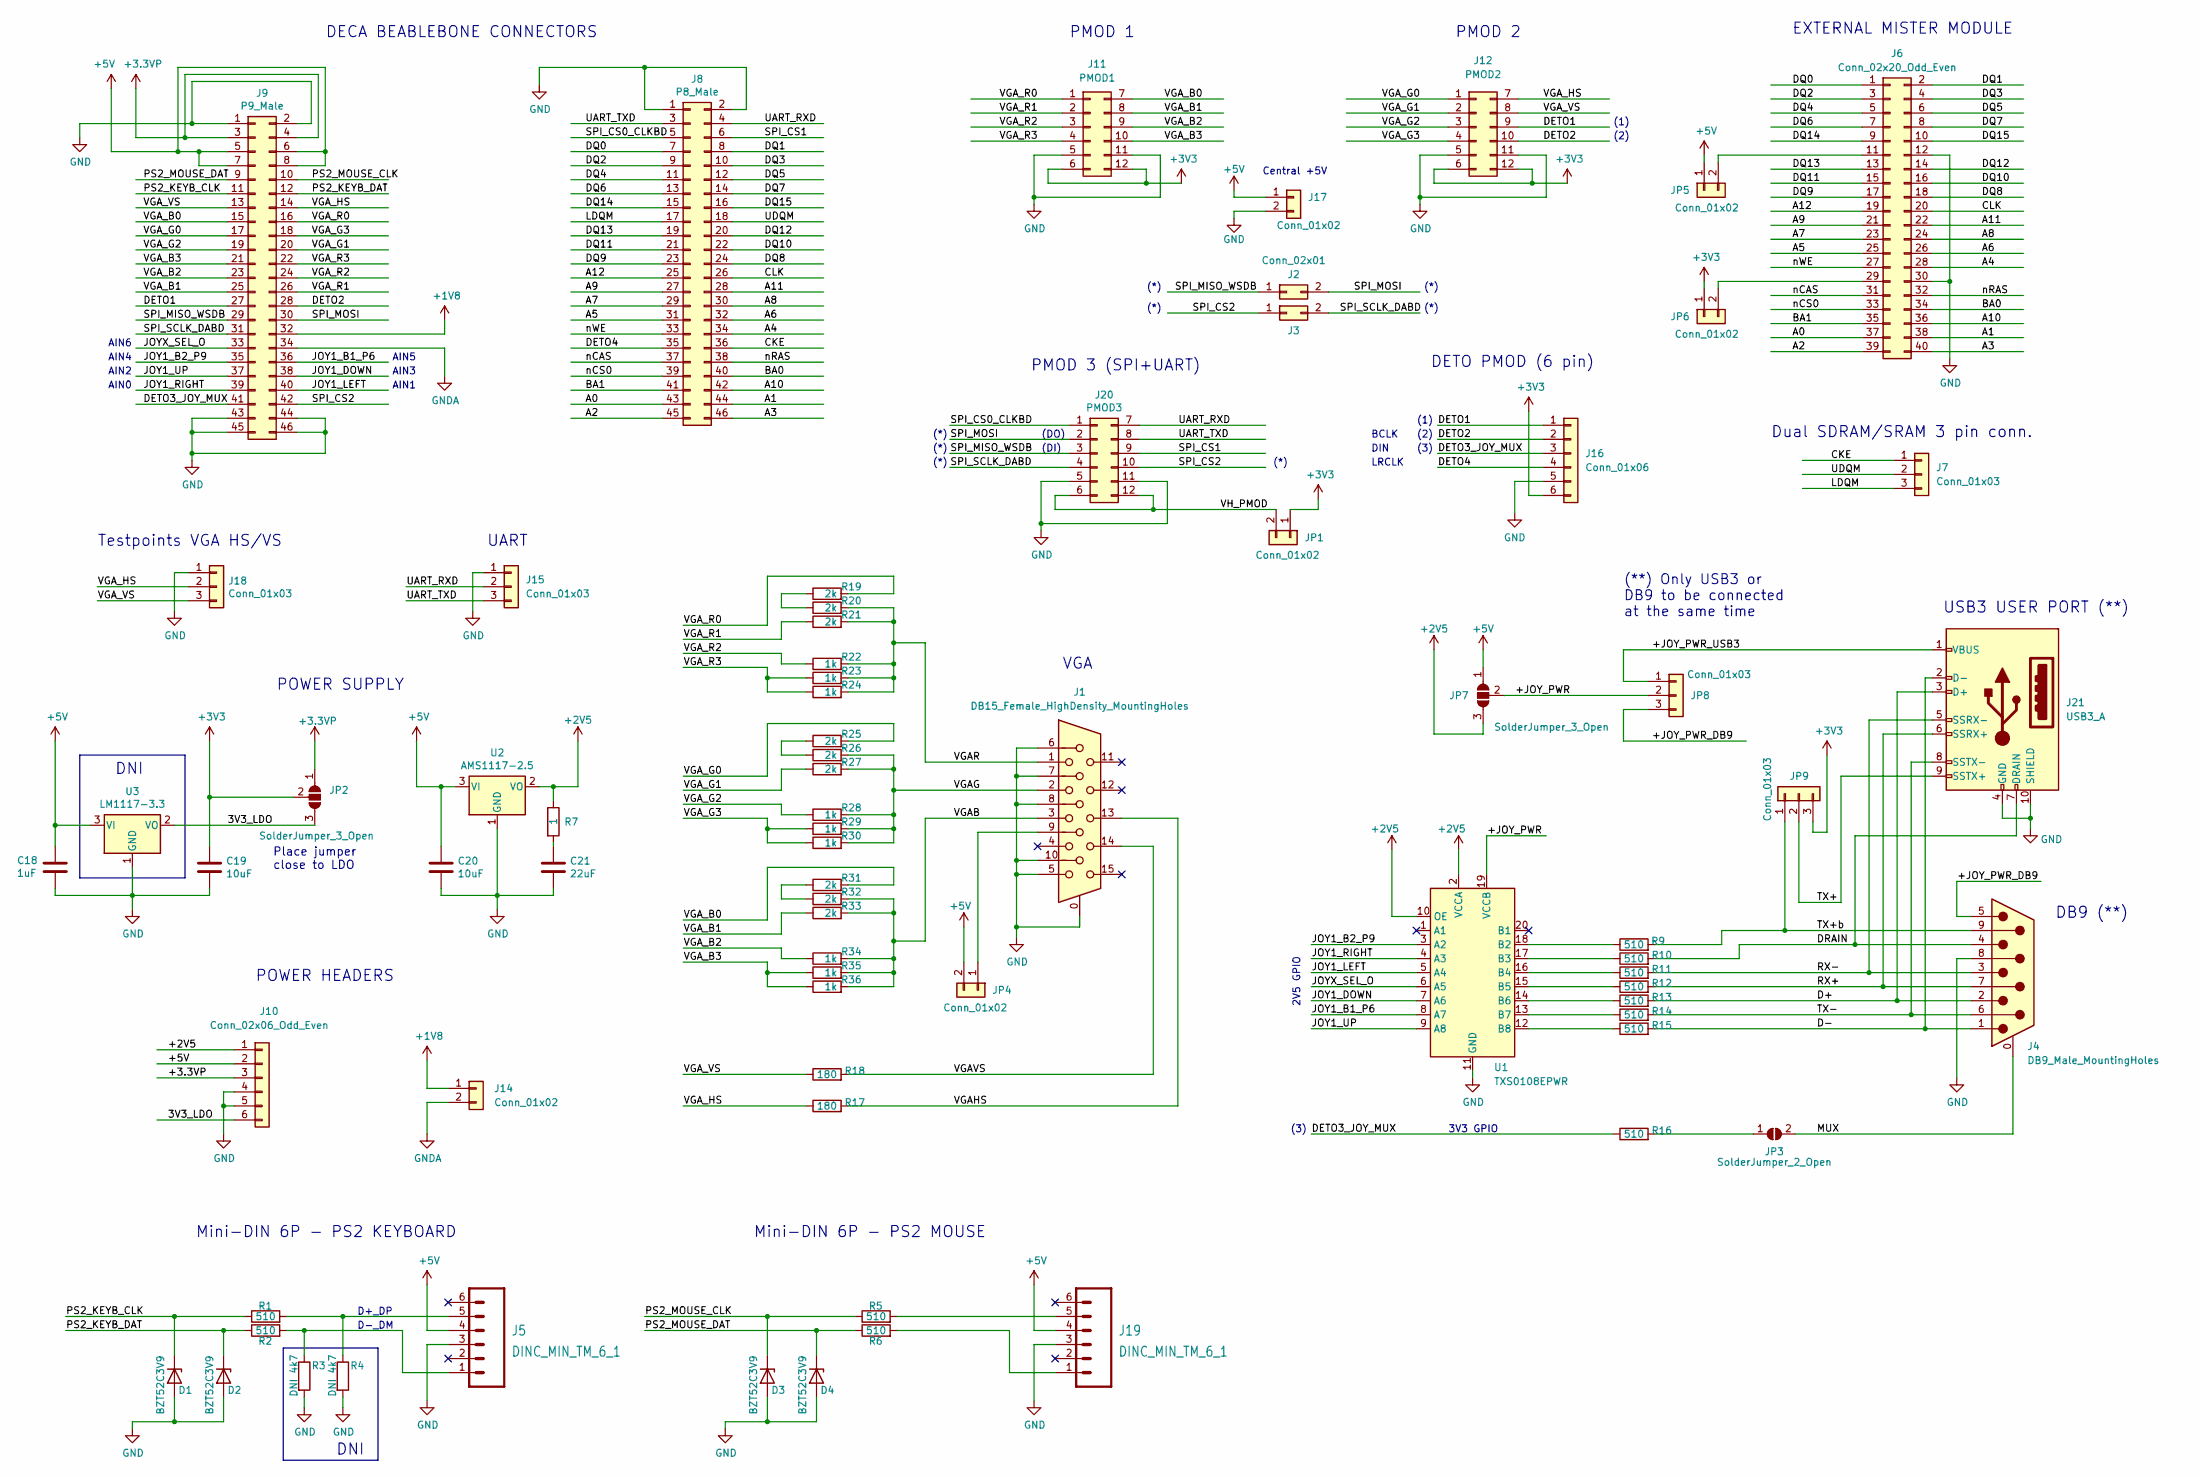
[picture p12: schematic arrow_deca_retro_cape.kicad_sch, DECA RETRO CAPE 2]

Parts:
C18: 1uF; C_0805_2012Metric_Pad1.18x1.45mm_HandSolder
C19, C20: 10uF; C_0805_2012Metric_Pad1.18x1.45mm_HandSolder
C21: 22uF; C_0805_2012Metric_Pad1.18x1.45mm_HandSolder
D1, D2, D3, D4: BZT52C3V9; D_SOD-123
J1: DB15_Female_HighDensity_MountingHoles; DSUB-15-HD_Female_Horizontal_P2.29x1.98mm_EdgePinOffset3.03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
J2, J3: Conn_02x01; PinSocket_1x02_P2.54mm_Vertical
J4: DB9_Male_MountingHoles; DSUB-9_Male_Horizontal_P2.77x2.84mm_EdgePinOffset9.90mm_Hou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
J5, J19: DINC_MIN_TM_6_1; DINC_MIN_TM_6_1PRIMARY
J6: Conn_02x20_Odd_Even; PinHeader_2x20_P2.54mm_Vertical
J7: Conn_01x03; PinSocket_1x03_P2.54mm_Vertical
J8: P8_Male; PinHeader_2x23_P2.54mm_Vertical
J9: P9_Male; PinHeader_2x23_P2.54mm_Vertical
J10: Conn_02x06_Odd_Even; PinSocket_1x06_P2.54mm_Vertical
J11: PMOD1; Pmod_2x06_P2.54mm_Vertical_2
J12: PMOD2; Pmod_2x06_P2.54mm_Vertical_2
J14, J17: Conn_01x02; PinSocket_1x02_P2.54mm_Vertical
J15, J18: Conn_01x03; PinHeader_1x03_P2.54mm_Vertical
J16: Conn_01x06; PinSocket_1x06_P2.54mm_Vertical
J20: PMOD3; PMOD_Female_Horizontal_2
J21: USB3_A; USB-3.0-TH_C69073
JP1, JP4, JP5, JP6: Conn_01x02; PinHeader_1x02_P2.54mm_Vertical
JP2, JP7: SolderJumper_3_Open; SolderJumper-3_P2.0mm_Open_TrianglePad1.0x1.5mm
JP3: SolderJumper_2_Open; SolderJumper-2_P1.3mm_Open_RoundedPad1.0x1.5mm
JP8, JP9: Conn_01x03; PinHeader_1x03_P2.54mm_Vertical
R1, R2, R5, R6, R9, R10, R11, R12, R13, R14, R15, R16: 510; R_0805_2012Metric_Pad1.20x1.40mm_HandSolder
R3, R4: DNI 4k7; R_0805_2012Metric_Pad1.20x1.40mm_HandSolder
R7: 1; R_0805_2012Metric_Pad1.20x1.40mm_HandSolder
R17, R18: 180; R_0805_2012Metric_Pad1.20x1.40mm_HandSolder
R19, R20, R21, R25, R26, R27, R31, R32, R33: 2k; R_0805_2012Metric_Pad1.20x1.40mm_HandSolder
R22, R23, R24, R28, R29, R30, R34, R35, R36: 1k; R_0805_2012Metric_Pad1.20x1.40mm_HandSolder
U1: TXS0108EPWR; TSSOP-20_4.4x6.5mm_P0.65mm
U2: AMS1117-2.5; SOT-223-3_TabPin2
U3: LM1117-3.3; SOT-223-3_TabPin2

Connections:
+1V8: J9.32, J14.1
+2V5: J10.1, JP7.3 (B), R7.1, U1.2 (VCCA), U1.10 (OE), U2.2 (VO)
+3.3VP: J9.3, J9.4, J10.3, JP2.1 (A)
+3V3: C19.1, J11.6, J11.12, J12.6, J12.12, J16.6, JP1.1, JP2.2 (C), JP6.1, JP9.3
+5V: C18.1, C20.1, J5.4, J9.5, J9.6, J9.7, J9.8, J10.2, J17.1, J19.4, JP4.2, JP5.1, JP7.1 (A), U2.3 (VI), U3.3 (VI)
/3V3_LDO: J10.6, JP2.3 (B), U3.2 (VO)
/+JOY_PWR: JP7.2 (C), JP8.2, U1.19 (VCCB)
/+JOY_PWR_DB9: J4.5, JP8.3
/+JOY_PWR_USB3: J21.1 (VBUS), JP8.1
/A0: J6.37, J8.43
/A1: J6.38, J8.44
/A2: J6.39, J8.45
/A3: J6.40, J8.46
/A4: J6.28, J8.34
/A5: J6.25, J8.31
/A6: J6.26, J8.32
/A7: J6.23, J8.29
/A8: J6.24, J8.30
/A9: J6.21, J8.27
/A10: J6.36, J8.42
/A11: J6.22, J8.28
/A12: J6.19, J8.25
/BA0: J6.34, J8.40
/BA1: J6.35, J8.41
/CKE: J7.1, J8.36
/CLK: J6.20, J8.26
/D+: J4.2, J21.3 (D+), R13.2
/D-: J4.1, J21.2 (D-), R15.2
/DETO1: J9.27, J12.9, J16.1
/DETO2: J9.28, J12.10, J16.2
/DETO3_JOY_MUX: J9.41, J16.3, R16.1
/DETO4: J8.35, J16.4
/DQ0: J6.1, J8.7
/DQ1: J6.2, J8.8
/DQ2: J6.3, J8.9
/DQ3: J6.4, J8.10
/DQ4: J6.5, J8.11
/DQ5: J6.6, J8.12
/DQ6: J6.7, J8.13
/DQ7: J6.8, J8.14
/DQ8: J6.18, J8.24
/DQ9: J6.17, J8.23
/DQ10: J6.16, J8.22
/DQ11: J6.15, J8.21
/DQ12: J6.14, J8.20
/DQ13: J6.13, J8.19
/DQ14: J6.9, J8.15
/DQ15: J6.10, J8.16
/DRAIN: J4.4, J21.7 (DRAIN), R10.2
/JOY1_B1_P6: J9.36, U1.8 (A7)
/JOY1_B2_P9: J9.35, U1.3 (A2)
/JOY1_DOWN: J9.38, U1.7 (A6)
/JOY1_LEFT: J9.40, U1.5 (A4)
/JOY1_RIGHT: J9.39, U1.4 (A3)
/JOY1_UP: J9.37, U1.9 (A8)
/JOYX_SEL_O: J9.33, U1.6 (A5)
/LDQM: J7.3, J8.17
/MUX: J4.0 (PAD), JP3.2 (B)
/PS2_KEYB_CLK: D1.1 (K), J9.11, R1.1
/PS2_KEYB_DAT: D2.1 (K), J9.12, R2.1
/PS2_MOUSE_CLK: D3.1 (K), J9.10, R5.1
/PS2_MOUSE_DAT: D4.1 (K), J9.9, R6.1
/RX+: J4.7, J21.6 (SSRX+), R12.2
/RX-: J4.3, J21.5 (SSRX-), R11.2
/SPI_CS0_CLKBD: J8.5, J20.1
/SPI_CS1: J8.6, J20.9
/SPI_CS2: J3.1, J9.42, J20.10
/SPI_MISO_WSDB: J2.1, J9.29, J20.3
/SPI_MOSI: J2.2, J9.30, J20.2
/SPI_SCLK_DABD: J3.2, J9.31, J20.4
/TX+: J21.9 (SSTX+), JP9.2
/TX+b: J4.9, JP9.1, R9.2
/TX-: J4.6, J21.8 (SSTX-), R14.2
/UART_RXD: J8.4, J15.2, J20.7
/UART_TXD: J8.3, J15.3, J20.8
/UDQM: J7.2, J8.18
/VGAB: J1.3, R32.2, R33.2, R34.2, R35.2, R36.2
/VGAG: J1.2, R26.2, R27.2, R28.2, R29.2, R30.2
/VGAHS: J1.13, R17.2
/VGAR: J1.1, R20.2, R21.2, R22.2, R23.2, R24.2
/VGAVS: J1.14, R18.2
/VGA_B0: J9.15, J11.7, R31.2
/VGA_B1: J9.25, J11.8, R33.1
/VGA_B2: J9.23, J11.9, R34.1
/VGA_B3: J9.21, J11.10, R35.1, R36.1
/VGA_G0: J9.17, J12.1, R25.2
/VGA_G1: J9.20, J12.2, R27.1
/VGA_G2: J9.19, J12.3, R28.1
/VGA_G3: J9.18, J12.4, R29.1, R30.1
/VGA_HS: J9.14, J12.7, J18.2, R17.1
/VGA_R0: J9.16, J11.1, R19.2
/VGA_R1: J9.26, J11.2, R21.1
/VGA_R2: J9.24, J11.3, R22.1
/VGA_R3: J9.22, J11.4, R23.1, R24.1
/VGA_VS: J9.13, J12.8, J18.3, R18.1
/VH_PMOD: J20.6, J20.12, JP1.2
/nCAS: J6.31, J8.37
/nCS0: J6.33, J8.39
/nRAS: J6.32, J8.38
/nWE: J6.27, J8.33
GND: C18.2, C19.2, C20.2, C21.2, D1.2 (A), D2.2 (A), D3.2 (A), D4.2 (A), J1.0, J1.5, J1.6, J1.7, J1.8, J1.10, J4.8, J5.3, J6.12, J6.30, J8.1, J8.2, J9.1, J9.2, J9.43, J9.44, J9.45, J9.46, J10.4, J10.5, J11.5, J11.11, J12.5, J12.11, J15.1, J16.5, J17.2, J18.1, J19.3, J20.5, J20.11, J21.4 (GND), J21.10 (SHIELD), R3.2, R4.2, U1.11 (GND), U2.1 (GND), U3.1 (GND)
GNDA: J9.34, J14.2
unnamed: C21.1, R7.2
unnamed: J1.9, JP4.1
unnamed: J5.1, R2.2, R3.1
unnamed: J5.5, R1.2, R4.1
unnamed: J6.11, JP5.2
unnamed: J6.29, JP6.2
unnamed: J19.1, R6.2
unnamed: J19.5, R5.2
unnamed: JP3.1 (A), R16.2
unnamed: R9.1, U1.18 (B2)
unnamed: R10.1, U1.17 (B3)
unnamed: R11.1, U1.16 (B4)
unnamed: R12.1, U1.15 (B5)
unnamed: R13.1, U1.14 (B6)
unnamed: R14.1, U1.13 (B7)
unnamed: R15.1, U1.12 (B8)
unnamed: R19.1, R20.1
unnamed: R25.1, R26.1
unnamed: R31.1, R32.1

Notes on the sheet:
(*)
D-_DM
POWER HEADERS
Testpoints VGA HS/VS
Dual SDRAM/SRAM 3 pin conn.
AIN2
BCLK
AIN6
Central +5V
PMOD 2
PMOD 1
DB9 (**)
DIN
(**) Only USB3 or DB9 to be connected at the same time
POWER SUPPLY
DNI
2V5 GPIO
LRCLK
(2)
AIN5
DECA BEABLEBONE CONNECTORS
(DI)
AIN0
3V3 GPIO
(3)
AIN4
Place jumper close to LDO
USB3 USER PORT (**)
AIN3
Mini-DIN 6P - PS2 MOUSE
PMOD 3 (SPI+UART)
UART
D+_DP
Mini-DIN 6P - PS2 KEYBOARD
(1)
DETO PMOD (6 pin)
(DO)
EXTERNAL MISTER MODULE
AIN1
VGA

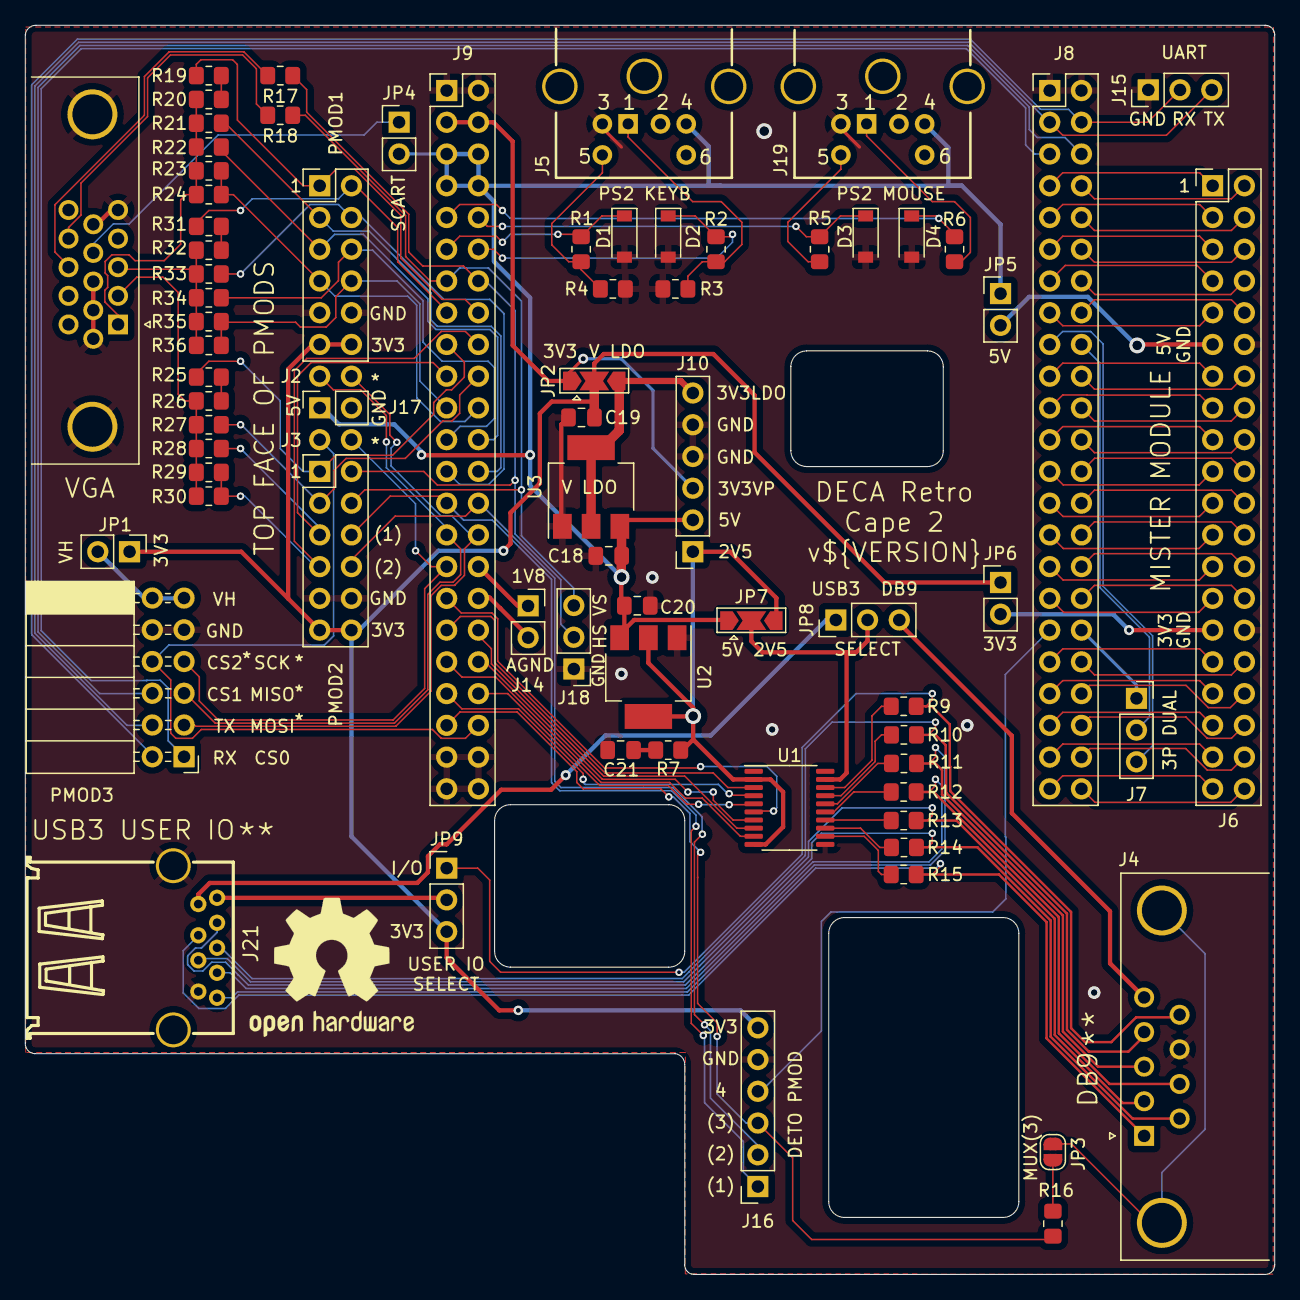
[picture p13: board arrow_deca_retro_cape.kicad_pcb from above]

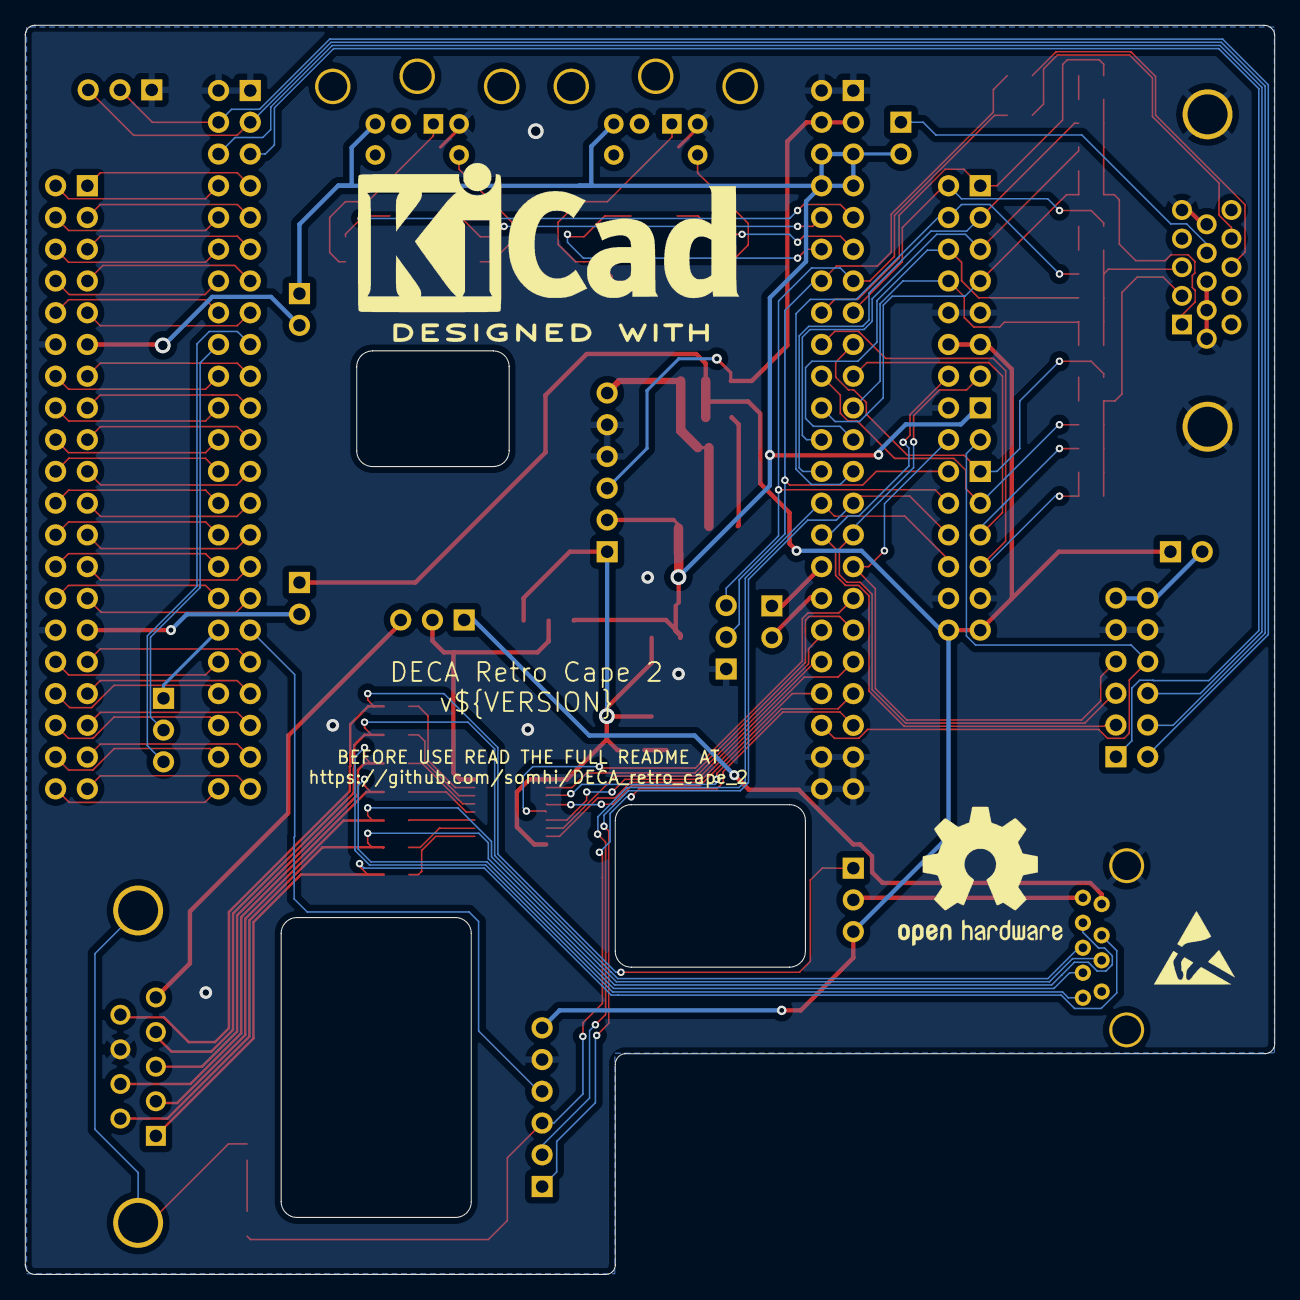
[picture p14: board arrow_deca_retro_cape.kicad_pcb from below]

Board: 2 copper layers, 100.0 x 100.0 mm, 79 parts (3 on the bottom side), 121 nets.

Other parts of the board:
LO1: KiCad-Logo2_12mm_SilkScreen
LO2, LO3: OSHW-Logo2_14.6x12mm_SilkScreen
LO4: ESD-Logo_6.6x6mm_SilkScreen

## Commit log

2022-03-11 v0.61 2-layer. Edge removed
    [arrow_deca_retro_cape.kicad_pcb, arrow_deca_retro_cape.kicad_sch]
2022-03-13 v0.62 only vga routing missing
    [DECA_Cape1_multicomputer_v0.51_WIP.ods, arrow_deca_retro_cape.kicad_pcb, arrow_deca_retro_cape.kicad_sch]
2022-03-13 v0.62 final without vga
    [arrow_deca_retro_cape.kicad_pcb, arrow_deca_retro_cape.kicad_sch]
2022-03-13 v0.65 power header changed
    [arrow_deca_retro_cape.kicad_pcb, arrow_deca_retro_cape.kicad_sch]
2022-03-13 v0.68 vga schematic
    [arrow_deca_retro_cape.kicad_pcb, arrow_deca_retro_cape.kicad_sch]
2022-03-13 v0.7 routing finished including vga
    [arrow_deca_retro_cape.kicad_pcb]
2022-03-13 updated readme and routing improvement
    [arrow_deca_retro_cape-B_Cu.gbr, arrow_deca_retro_cape-B_Mask.gbr, arrow_deca_retro_cape-B_Paste.gbr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]
2022-03-15 v0.71 gerbers sent for manufacturing
    [DECA_Cape1_multicomputer_v0.71.ods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]
2022-04-09 updated status. received pcb. started testing
    [arrow_deca_retro_cape.kicad_pcb, arrow_deca_retro_cape.kicad_sch, arrow_deca_retro_cape.ods]
2022-04-12 updated materials list
    [arrow_deca_retro_cape.ods]
2022-05-03 v0.72 updated readme and pinout spreadsheet
    [DECA_Cape1_multicomputer_v0.71.ods, DECA_Cape1_multicomputer_v0.72.ods, arrow_deca_retro_cape-BOM.ods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]
2022-11-24 v0.75 see changelog
    [arrow_deca_retro_cape-BOM.ods, arrow_deca_retro_cape.kicad_pcb, arrow_deca_retro_cape.kicad_sch]
2022-11-24 v0.76 double pmod added 4 central pins
    [DECA_Cape1_multicomputer_v0.72.ods, DECA_Cape1_multicomputer_v0.76.ods, arrow_deca_retro_cape.kicad_pcb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]
2022-11-26 v0.77 see changelog
    [arrow_deca_retro_cape.kicad_pcb, arrow_deca_retro_cape.kicad_sch]
2022-11-27 v0.78 ps2 protections with zeners
    [arrow_deca_retro_cape-BOM.ods, arrow_deca_retro_cape.kicad_pcb, arrow_deca_retro_cape.kicad_sch]
2022-12-08 v0.80 WIP adding level shifter for db9/usb3
    [arrow_deca_retro_cape.kicad_pcb, arrow_deca_retro_cape.kicad_sch]
2022-12-08 v0.8 routing ended for level shifter
    [arrow_deca_retro_cape.kicad_pcb, arrow_deca_retro_cape.kicad_sch]
2022-12-09 v0.81 minor updates. Improved readme
    [arrow_deca_retro_cape.kicad_pcb, arrow_deca_retro_cape.kicad_sch]
2022-12-16 v0.82 generated BOM before install. jlcpcb-tools plugin
    [arrow_deca_retro_cape-BOM_OLD.ods, arrow_deca_retro_cape.csv, arrow_deca_retro_cape.kicad_pcb]
2022-12-22 v0.83 Added jlcpcb parts with jlcpcb tools plugin
    [PCB_NEW_PCB_2022-12-20.kicad_pcb, arrow_deca_retro_cape-BOM_OLD.ods, arrow_deca_retro_cape.kicad_pcb]
2022-12-22 v0.84 updated USB3 footprint
    [arrow_deca_retro_cape-BOM_OLD.ods, arrow_deca_retro_cape.kicad_pcb, arrow_deca_retro_cape.kicad_sch]
2022-12-24 v0.85 reorganized references. Added Zener 3V9 reference
    [arrow_deca_retro_cape-BOM_OLD.ods, arrow_deca_retro_cape.kicad_pcb]
2022-12-24 v0.86 updated datasheets, added R7
    [arrow_deca_retro_cape-BOM_OLD.ods, arrow_deca_retro_cape.csv, arrow_deca_retro_cape.kicad_pcb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]
2022-12-25 v0.87 updated readme and minor changes sch&pcb
    [arrow_deca_retro_cape-BOM_v0.86.ods, arrow_deca_retro_cape.csv, arrow_deca_retro_cape.kicad_pcb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]
2022-12-26 v0.90 finalized gerger, bom and cpl files ready for jlcpcb production
    [BOM-arrow_deca_retro_cape.csv, BOM-arrow_deca_retro_cape_v0.90.csv, DECA_Cape1_multicomputer_v0.76.ods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]
2023-01-23 Updated JLCPCB BOM, deleted gerber files not used
    [BOM-arrow_deca_retro_cape.csv, BOM-arrow_deca_retro_cape_v0.90.csv, arrow_deca_retro_cape-BOM_old.ods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]
2023-01-31 updated BOM of v0.90
    [arrow_deca_retro_cape-BOM_v0.90.ods, arrow_deca_retro_cape.csv]
2023-02-05 update comments on DECA pinout
    [DECA_retro_cape_2_Pinout_v0.90.ods]
2023-03-03 minor schematic notes update
    [arrow_deca_retro_cape-BOM_v0.90.ods, arrow_deca_retro_cape.kicad_sch]
2023-04-01 pinout update sigma_l, sigma_r
    [DECA_retro_cape_2_Pinout_v0.90.ods]
2023-05-30 updated readme and minor pinout
    [DECA_retro_cape_2_Pinout_v0.90.ods]
